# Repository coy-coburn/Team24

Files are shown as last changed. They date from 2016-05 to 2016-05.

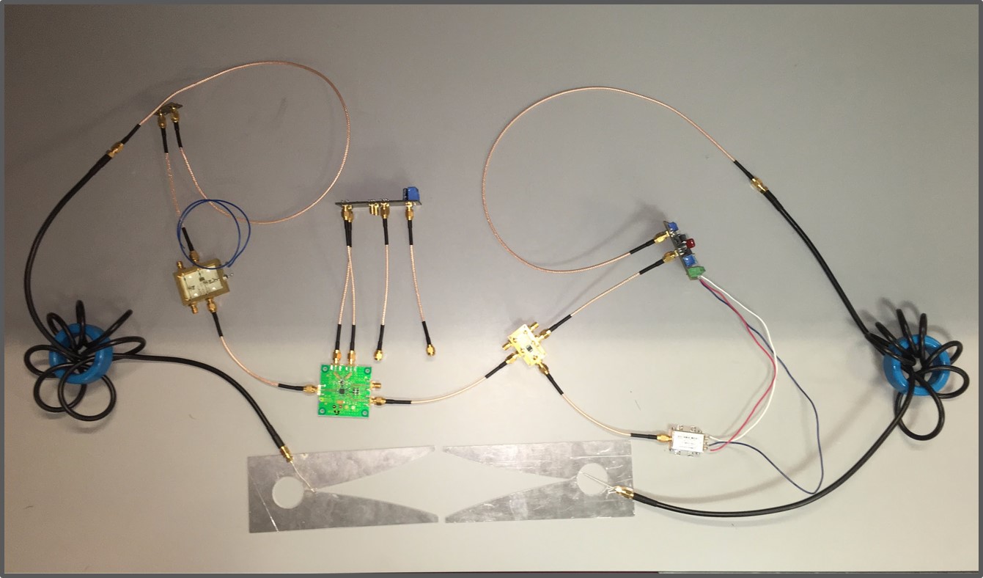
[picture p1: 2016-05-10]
photos/System.jpg

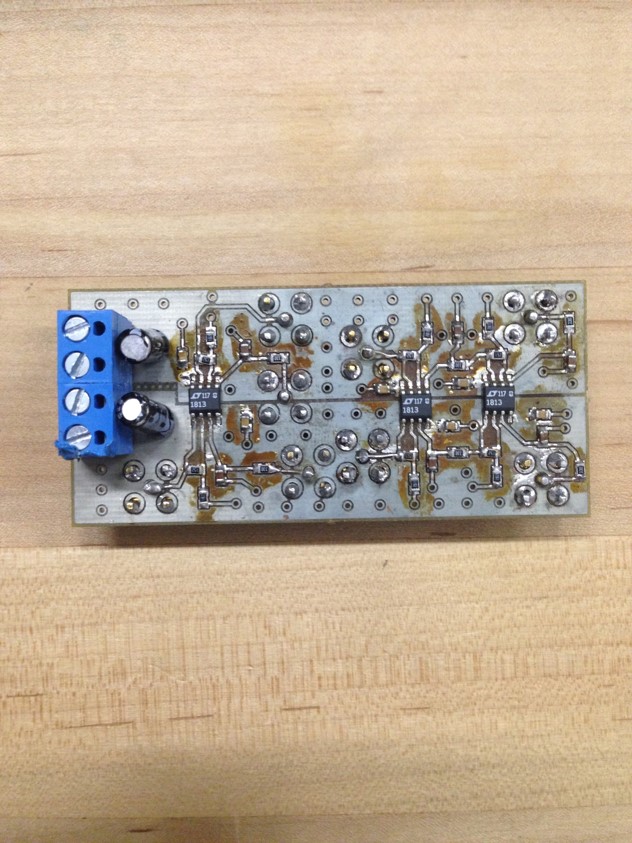
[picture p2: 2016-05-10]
photos/Filter.jpg

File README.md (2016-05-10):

# Ground Breakers
####Ground Penetrating Radar Github

The goal of this project is to create a ground penetrating radar system to serve as a non-destructive method for mapping plant root systems. The system consists of a transmitting and receiving antenna and circuitry for both the transmitter and receiver. The transmitting circuit generates a linear frequency-modulated continuous wave from 2.415- 2.425GHz. The wave is pulsed to avoid interference between the transmitting and receiving antenna. The transmitting antenna passes the generated signal into the ground while the receiving antenna collects the reflected signal. The signal will reflect off materials with different dielectric constants like that of roots and pipes. The received signal will then be sent through an LNA for amplification to balance any loss of gain. The signal is also fed into a frequency mixer to correct any occured frequency shift. Finally, the IF signal is converted into digital data that will be recorded for image processing.

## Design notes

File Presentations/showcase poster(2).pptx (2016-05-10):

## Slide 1

Root Mapping with Ground Penetrating Radar
Sponsor: Dr. Mark Everett (GEOP)
Professor: Dr. Chadi Geha TA: Neal Hollingsworth
Team members: Tyler Castro, Coy Coburn, Daniel Miller, Michael Turner

Abstract/Overview
A ground penetrating radar system (GPRS) detects objects beneath the surface by measuring a reflected electromagnetic wave and matching the reflected signal with the incident wave. After data processing, an object's depth and even the object’s material can be determined. This helps geophysics to map root growth over a period of time in a nondestructive way. Unlike other GPRS, our system uses higher frequencies (2.415-2.425GHz) in order to improve resolution.

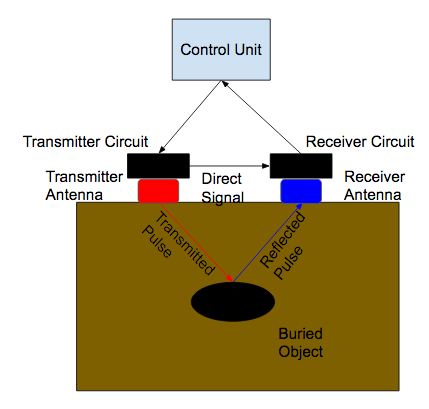
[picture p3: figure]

Figure 1. General Concept of GPRS

Signal Generation
(Linear Frequency Modulated Waveform)
A linear frequency modulated waveform is generated using a function generator and a Voltage Controlled Oscillator (VCO). This type of waveform is generated so that the frequency domain can be utilized versus the time domain. This is important in that as a signal passes through different media, the frequency of the signal remains constant. This allows the frequency to be matched on the received side so that time and amplitude can then be measured more accurately versus the time domain.

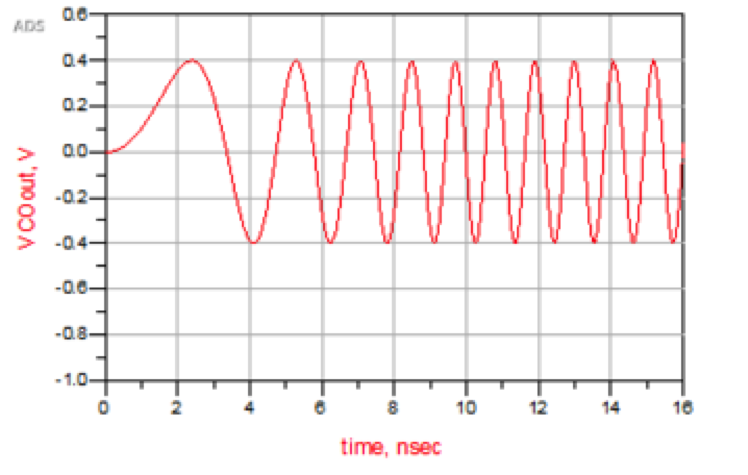
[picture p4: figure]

Figure 5: Linear Frequency Modulated Waveform

Receiver Protection and LNA
Before the signal is passed to the mixer it is conditioned to make use of the whole dynamic range of the AD converter. This is done by passing the signal through an LNA (Low Noise Amplifier). To protect the LNA from high power spikes, such as ones generated by the air to ground reflection, a schottky diode clamp is added between the LNA and the antenna. The schottky activation range is between the LNA compression point and the LNA maximum input power. LNA compression point is calculated by taking the difference between the output power at 1dB compression and the gain obtained by the LNA

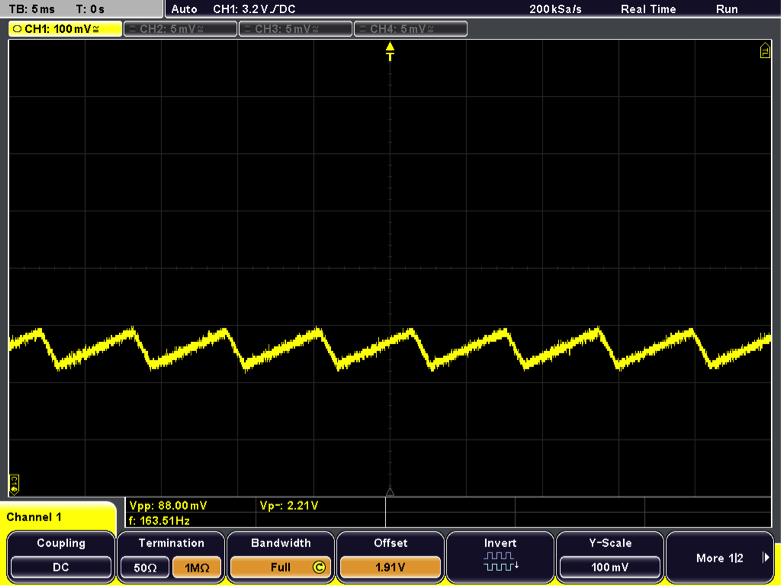
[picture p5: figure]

Figure 4: Function Generator output

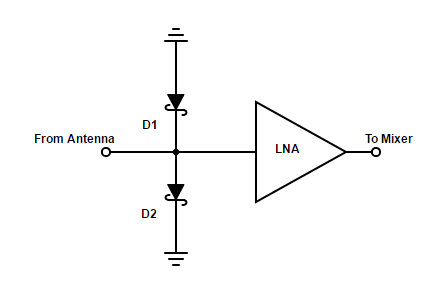
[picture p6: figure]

Figure 7. Receiver Protection and LNA circuit

AD Conversion
The filtered IFP and IFN are passed through the ADC driver for buffering and adjusting amplitude before reaching the ADC. A AAF is also included to ensure the cutoff frequency from previous stages is still entailed. Finally, an ADC with at least twice the sampling rate of the Nyquist frequency, in this case the bandwidth, is used to get the needed samples to accurately convert the analog signal into its digital counterpart.

Vivaldi Antennas
Two Vivaldi Antennas set to transmit at a frequency between 2.4025 - 2.4775 GHz. The antennas operate as a slot hole that increases in width exponentially, eventually matching the impedance of the signal with air. Ferrite cores were used to create RF chokes which acted as baluns for the system, allowing for the unbalanced coaxial cable to transition into the balanced antenna.

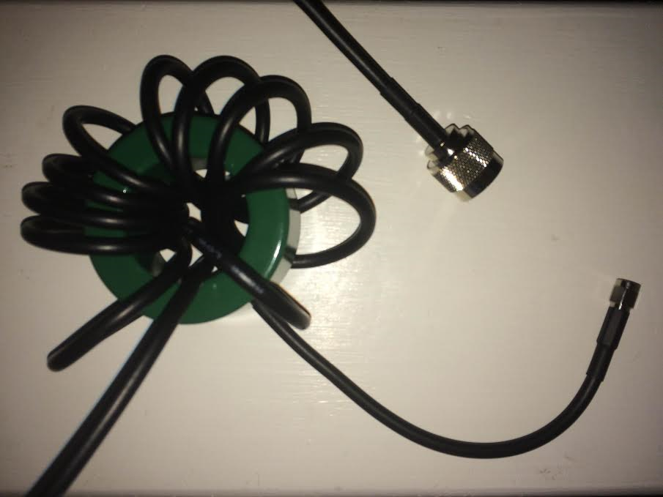
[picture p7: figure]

Reflected Signal Mixing and Filtering
Once the Rx has been amplified by the LNA, it must be mixed with the original baseline transmitted signal. Feeding the Rx into the RF input and the Tx into the LO port, an IF signal is produced. The signal is output in differential components to provide noise immunity as well as a cancellation on even-order harmonics. Calculations illustrate an expectec IF signal of 200kHz.
The IF outputs are passed through a filtering stage for image rejection. Cutoff frequencies of 250 kHz are chosen to not only prevent the up conversion image to pass, but also to protect from any unexpected IF spikes during changes in rising and falling RF/LO frequencies.

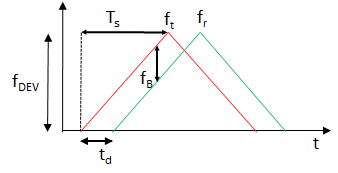
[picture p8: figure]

Figure 6. Frequency vs Time representation of LO signal compared to the RF signal

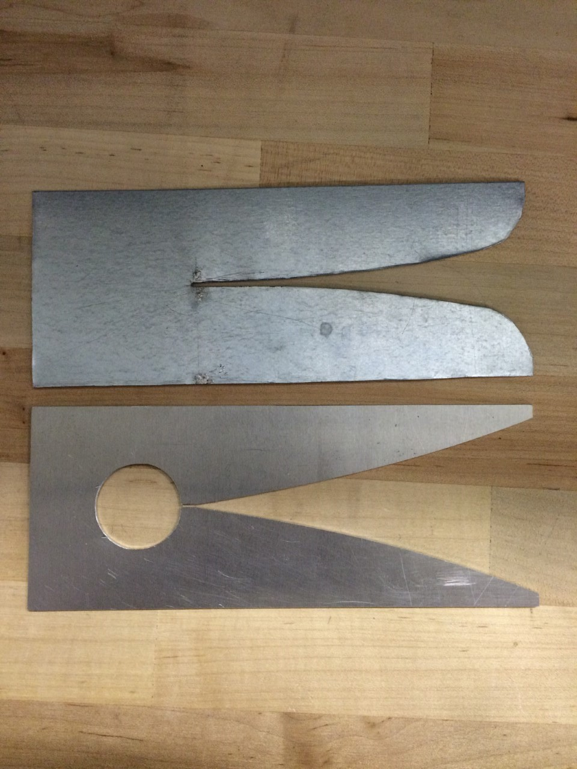
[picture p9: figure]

Figure 2. Vivaldi antennas, version 1 (top) and version 2 (below).
Figure 3. Ferrite core with coaxial cable wrapped around it, creates reactance along the outside of the cable

Rx MIXER

LO

Power Splitter

Receiver Conversion Subsystem

Figure 8. Receiver subsystem block diagram

Schottky

LNA

RF

IFP
IFN

LPF

ADC Driver

AAF

ADC

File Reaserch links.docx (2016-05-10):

http://www.geo-sense.com/GPRmore.htm - brief GPR description

http://compass.astm.org/EDIT/html_annot.cgi?D6432+11 - long detailed GPR descriptions - has many useful charts

http://www.sensoft.ca/FAQ.aspx - GPR stuff

http://georadar.150m.com/ - GPR stuff

http://epubs.surrey.ac.uk/973/1/fulltext.pdf - Long paper on GPR mostly about antennas - also old so not a lot of the data may be relevant today

http://www.sic.rma.ac.be/~scheers/Papers/chapter2.pdf - GPR design

http://d2dtl5nnlpfr0r.cloudfront.net/tti.tamu.edu/documents/1702-S.pdf - GPR Prototype development

http://ieeexplore.ieee.org/xpl/login.jsp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 - Essentially Referenced by all papers I found. The godfather of the Vivaldi Antenna

http://www.rfwireless-world.com/calculators/slotline-calculator.html - slotline equations

http://www.antenna-theory.com/antennas/aperture/vivaldi.php - makeshift vivaldi antenna guide

http://www.jpier.org/PIER/pier82/26.08040601.pdf - Exponential curve equations

https://www.eznec.com/Amateur/Articles/Baluns.pdf - Helpful reference for baluns

http://www.jpole-antenna.com/2012/07/03/why-build-antennas-out-of-copper-and-not-aluminum-or-stainless-steel/ - Quick advice on material choice (hint: don't pick aluminum)

http://www.futureelectronics.com/en/diodes/schottky-diodes.aspx - Schottky Diode description

https://www.ieee.li/pdf/essay/pin_diode_handbook.pdf - PIN Diode Handbook

http://publications.lib.chalmers.se/records/fulltext/163250.pdf - Fast PIN Diode driver design

http://www.analog.com/library/analogDialogue/archives/44-02/pin_diode.html - PIN Diode Driver

http://www.ittc.ku.edu/~jstiles/622/handouts/Receiver%20Compression%20Point.pdf – Receiver Compression

http://www.microwaves101.com/encyclopedias/compression-point - Compression Point

http://cp.literature.agilent.com/litweb/pdf/5965-8166E.pdf - Using Network Analyzer

http://www.analog.com/library/analogDialogue/archives/39-06/Chapter%205%20Testing%20Converters%20F.pdf – Analog digital conversion

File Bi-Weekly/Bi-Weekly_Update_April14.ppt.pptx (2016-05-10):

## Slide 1

Team 24 - Ground Penetrating Radar

Members: Tyler Castro, Coy Coburn, Daniel Miller, and Michael Turner

Design and simulate subsystems | Buy necessary hardware | Incorporate transmitter circuit and antenna | Incorporate receiver circuit and antenna | Integrate subsystems and testing with network analyzer

Transmitter Circuit

Transmitter Antenna

Control Unit

Direct Signal

Receiver Circuit

Receiver Antenna

Transmitted Pulse

Reflected Pulse

Buried Object

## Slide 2

Signal Generation Daniel Miller

Accomplishments since the last presentation ~35 hrs | Ongoing progress/problems and plans until the next presentation
Finished PCB Needs decoupling Tested Function Generated 5 MHz Bandwidth (80 mVpp) Voltage divider Start of ISM band (2V) Op-Amp | Solder PCB Prepare for Demo Problem: Excess Noise

VCO frequency equation:
frequency = 68.065 (Voltage) + 2268.8

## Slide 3

Output from Op-Amp

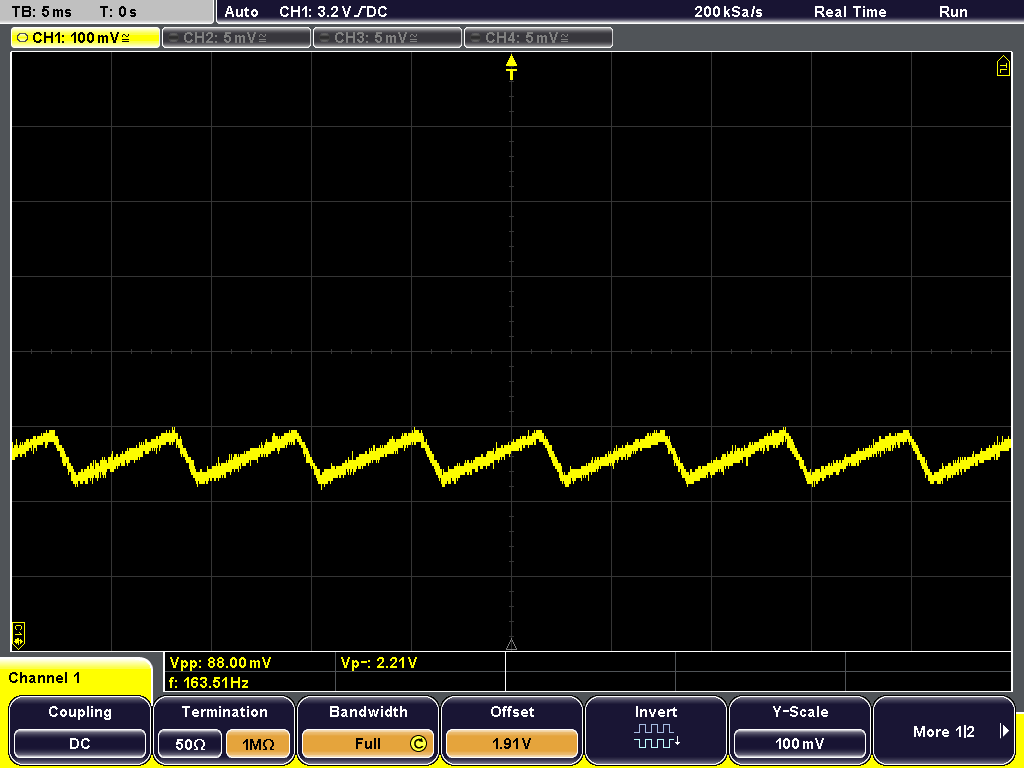
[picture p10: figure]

Vpp = 88mV
Vp = 2.21 V

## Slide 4

Antennas Tyler Castro

Accomplishments since the last presentation 30 hrs | Ongoing progress/problems and plans until the next presentation
Tested antenna created by hand Used Solidworks to create files for having the antennas made with the mill Currently working to ensure antennas get cut Ordered parts for demo | Ensure antennas are created in order to begin immediate testing Prepare for demo

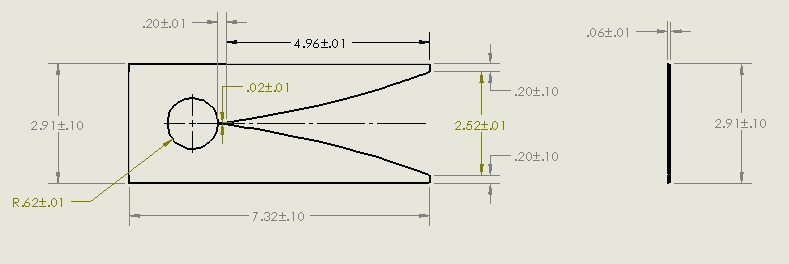
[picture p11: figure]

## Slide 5

Receiver Circuit Michael Turner

Accomplishments since the last presentation 20 hrs | Ongoing progress/problems and plans until the next presentation
Finished ordering parts and SMA cables Designed and received PCB Assisted Coy with redesign of receiver conversion and PCB design | Solder PCB Test Schottky diodes and LNA Work with Coy with integrating the receiver together

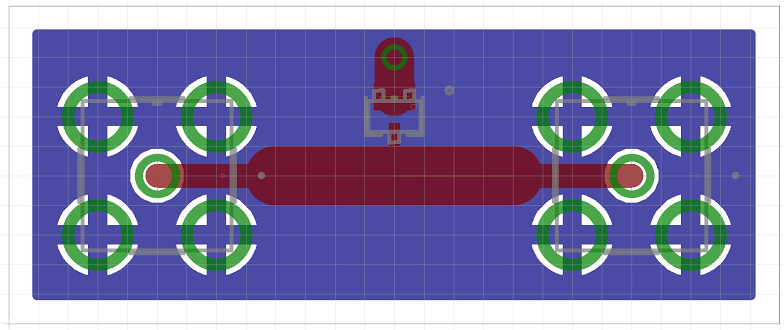
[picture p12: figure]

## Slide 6

Receiver Conversion Coy Coburn

Accomplishments since the last presentation 32 hrs | Ongoing progress/problems and plans until the next presentation
Redesigned and simulating receiver schematic Recalculated sampling rate data based on new bandwidth of 5MHz Bought chips,eval boards, and other hardware Designed and received PCB Found and bought power divider | Check necessary gain and corner freuencies for each LPF/AAF stage Locate ADC eval board and test digitization with Analog Visual Test ADC driver output Integrate circuit with Michael’s LNA/Schottky circuit

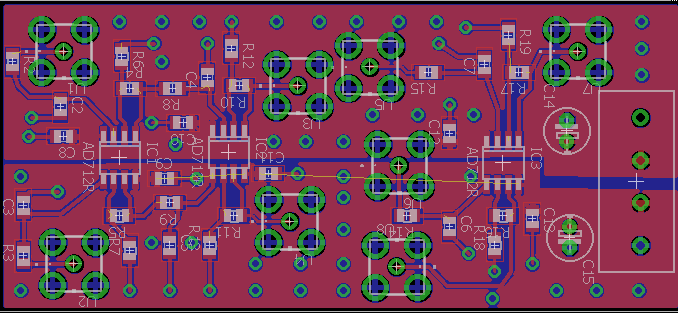
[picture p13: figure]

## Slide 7

Block Diagram and Parts Table

SHIELD

Schottky

IMAGE
REJECT
FILTER (LPF)

ADC Driver

AAF/LPF

LNA

Rx MIXER

IF Amp

LPF

ADC

Gain Block

Power Splitter

SHIELD

Block | Part number
Rx Mixer | ADL5363
Gain block | ADL5611
Low pass filter (LPF) op amps | LT1813
ADC Driver | AD8138
ADC | AD9280
Power Splitter | BP2U+

Gain Block

SHIELD

## Any Questions?

Thanks and Gig em’

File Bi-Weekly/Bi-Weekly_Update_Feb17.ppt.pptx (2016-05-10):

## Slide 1

Team:24 Ground Penetrating Radar

Design and simulate subsystems | Buy necessary hardware | Install transmitter and phased array antenna | Install receiver and phased array antenna | Integrate subsystems and testing with network analyzer | Design image processing system (if time)

Transmitter Circuit

Transmitter Antenna

Control Unit

Receiver Circuit

Receiver Antenna

Direct Signal

Transmitted Pulse

Reflected Pulse

Buried Object

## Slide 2

Power/Signal Generation Daniel Miller

Accomplishments since the last presentation ~20 hrs | Ongoing progress/problems and plans until the next presentation
Redefined requirements Power loss through media (not good estimate) Researched other ways to achieve bandwidth (DDS/NCO) | Meet with Professor Nevels Obtain antenna info (sensitivity/gain) Calculate power needed at output Power needed through system (PA)

Transmitter Circuit

Transmitter Antenna

Receiver Circuit

Receiver Antenna

Transmitted Pulse

Direct Signal

Reflected Pulse

Buried Object

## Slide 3

Receiver Circuit Michael Turner

Accomplishments since the last presentation 20 hrs | Ongoing progress/problems and plans until the next presentation
Redesigned Receiver circuit Bought LNAs Found possible PIN Diodes Research PIN Diode driver | Design PIN Diode Driver Decide on PIN Diode and order all parts

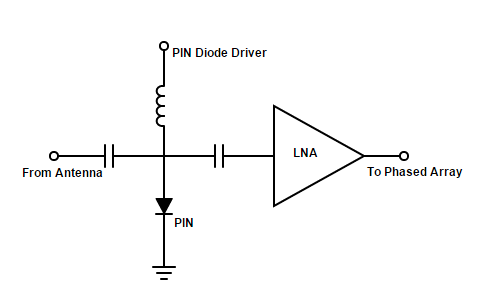
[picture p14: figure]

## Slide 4

Receiver Antenna Coy Coburn

Accomplishments since the last presentation 15 hrs | Ongoing progress/problems and plans until the next presentation
Calculated/bought necessary coax cable to create phase shifters Designing/simulating summing amp Researching mixers and IQ demodulation | Finalize receiver schematic Choose and order IQ demodulator and mixers (if needed)

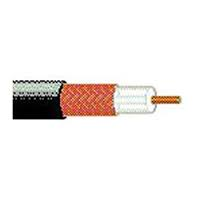
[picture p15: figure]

Belden 9258 specs:
Impedance: 50 Ω
Propagation Velocity: %82
Nominal Attenuation: 10.7 dB/100 ft @ 900 MHz
Price: $0.82 per ft

Length of coax: d = (Vf*c/ƒ)*(Θ/360)

30° | 45° | 60° | 90°
2.24 cm | 3.36 cm | 5.04 cm | 6.72 cm

Phase shift:
Length:

180°
13.44 cm

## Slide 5

Transmitting Antenna Tyler Castro

Accomplishments since the last presentation 15 hrs | Ongoing progress/problems and plans until the next presentation
Decided on specific amplifiers for gain stages Using Vivaldi antennas for directivity, simplicity and cost of construction Calculated design parameters for Vivaldi antennas | Order components to begin construction Design balun to prevent current from travelling along outside of coaxial cable at antenna connection

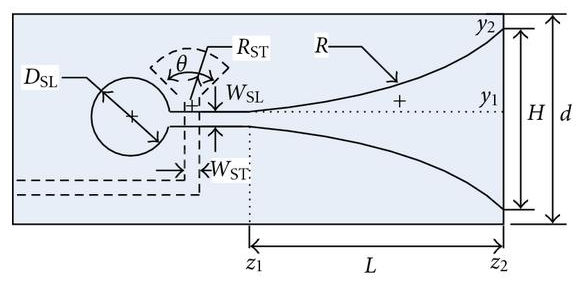
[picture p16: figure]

Vivaldi Antenna, facing right
For 700 MHz:
H = 8.44 inches
L = 16.87 inches
Dsl = 2.48 inches

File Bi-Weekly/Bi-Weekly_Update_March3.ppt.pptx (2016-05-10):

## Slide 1

Team:24 Ground Penetrating Radar

Design and simulate subsystems | Buy necessary hardware | Install transmitter and phased array antenna | Install receiver and phased array antenna | Integrate subsystems and testing with network analyzer | Design image processing system (if time)

Transmitter Circuit

Transmitter Antenna

Control Unit

Direct Signal

Receiver Circuit

Receiver Antenna

Transmitted Pulse

Reflected Pulse

Buried Object

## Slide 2

Receiver Circuit Michael Turner

Accomplishments since the last presentation 20 hrs | Ongoing progress/problems and plans until the next presentation
Added schottky diodes to protect LNA Ordered schottky diodes Work on simulation for PIN Diode driver | Finish PIN diode driver simulation Design PCB board Work with Coy to combine LNA and diode circuit with demodulator

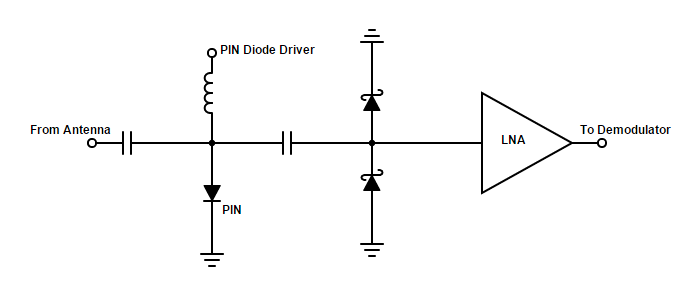
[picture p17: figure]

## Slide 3

Receiver Antenna Coy Coburn

Accomplishments since the last presentation 17 hrs | Ongoing progress/problems and plans until the next presentation
Redefined goals for GPR system Helped set excel doc to calculate needed variables Researching mixers and IQ demodulation | Finalize receiver schematic Choose and order IQ demodulator and ADC Work with Michael to combine LNA and diode circuit with demodulator

Sample rate(Fs): 2 * BW = 150 MHz = 150 Msamples/sec
Slope (freq/time): BW / 4 * TOF = 1.9 E 15 Hz/s
Freq resolution(Δf): (2*spatial resolution/ Vs)* Slope = 2.4MHz
Δf = 1/T T = #samples / Fs
#samples = 62.5 => 63 samples

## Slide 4

Transmitting Antenna Tyler Castro

Accomplishments since the last presentation 15 hrs | Ongoing progress/problems and plans until the next presentation
Purchased metal sheets and tools, began construction of prototype antenna Ordered balun parts | Finish construction, solder balun and begin running tests using network analyzer Use data to improve design

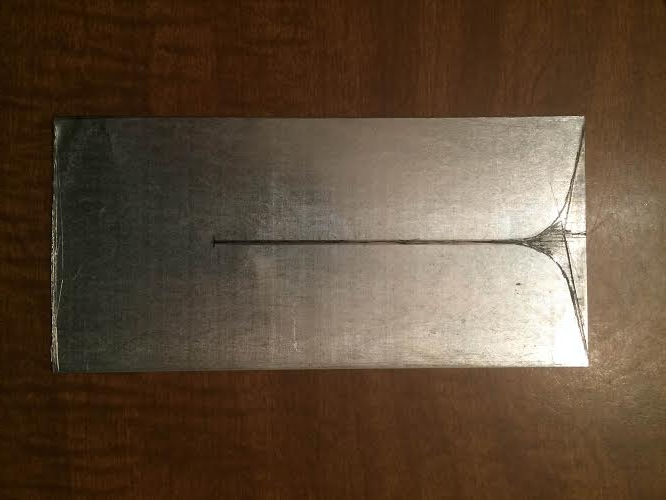
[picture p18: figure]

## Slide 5

Power/Signal Generation Daniel Miller

Accomplishments since the last presentation ~15 hrs | Ongoing progress/problems and plans until the next presentation
Ordered function generator up to 1 MHz meets pulse duration requirement (duty cycle) Ordered VCO ISM band 2-2.5V Minimum of 50 mW output for antennas | Test outputs from VCO Select/Order PA Think about portable power supply

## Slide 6

Function Generator circuit

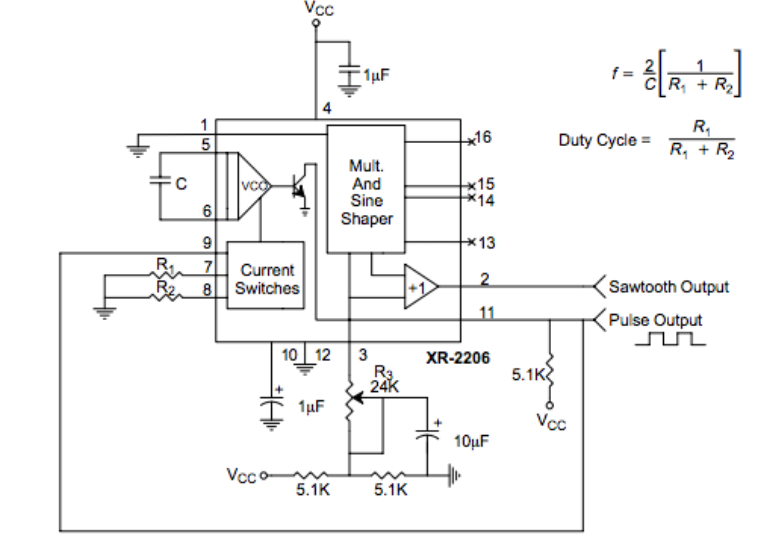
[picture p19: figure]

Jameco XR-2206 Data sheet

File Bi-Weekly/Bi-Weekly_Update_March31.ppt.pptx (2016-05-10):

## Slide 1

Team 24 - Ground Penetrating Radar

Design and simulate subsystems | Buy necessary hardware | Incorporate transmitter circuit and antenna | Incorporate receiver circuit and antenna | Integrate subsystems and testing with network analyzer | Design image processing system (if time)

Transmitter Circuit

Transmitter Antenna

Control Unit

Direct Signal

Receiver Circuit

Receiver Antenna

Transmitted Pulse

Reflected Pulse

Buried Object

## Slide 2

Power/Signal Generation Daniel Miller

Accomplishments since the last presentation ~18 hrs | Ongoing progress/problems and plans until the next presentation
Ordered PAs (Approx 1 W) 24 dB gain Output +26dBm Tested VCO (broken) Soldered wires to inputs Stripped coaxial to wire for testing Talked with manufacturer to ship new part Started PCB design | Test VCO .5-5V Vtune Finish designing PCB Test Function generator Think about portable power supply

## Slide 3

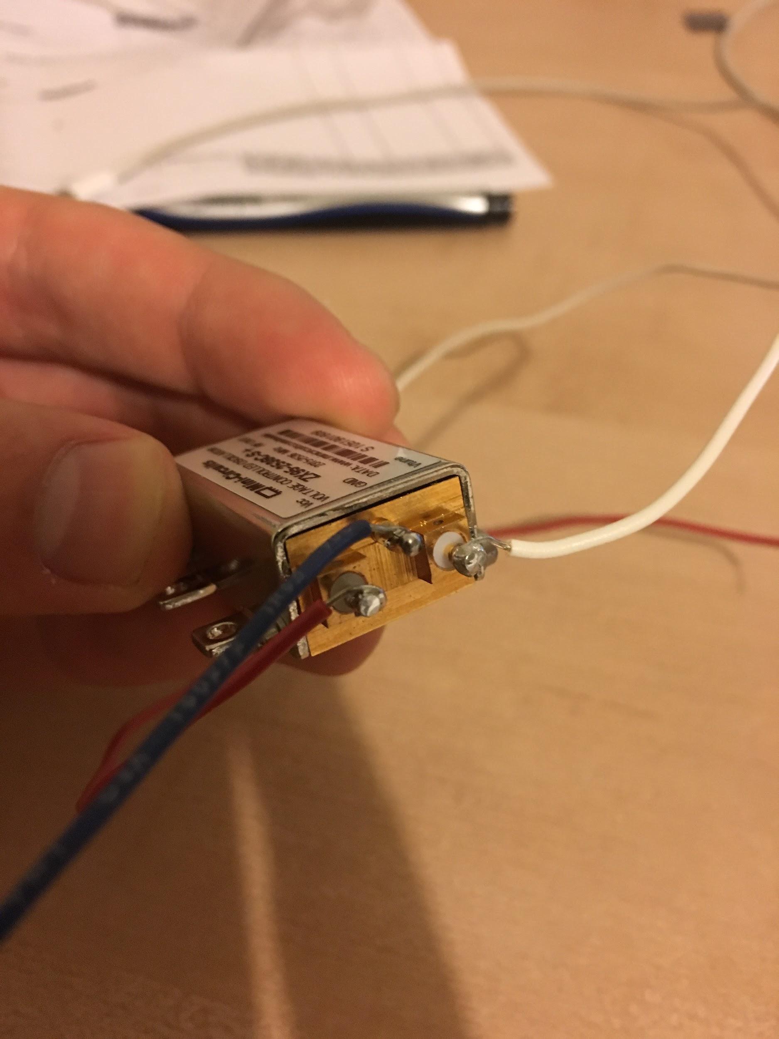
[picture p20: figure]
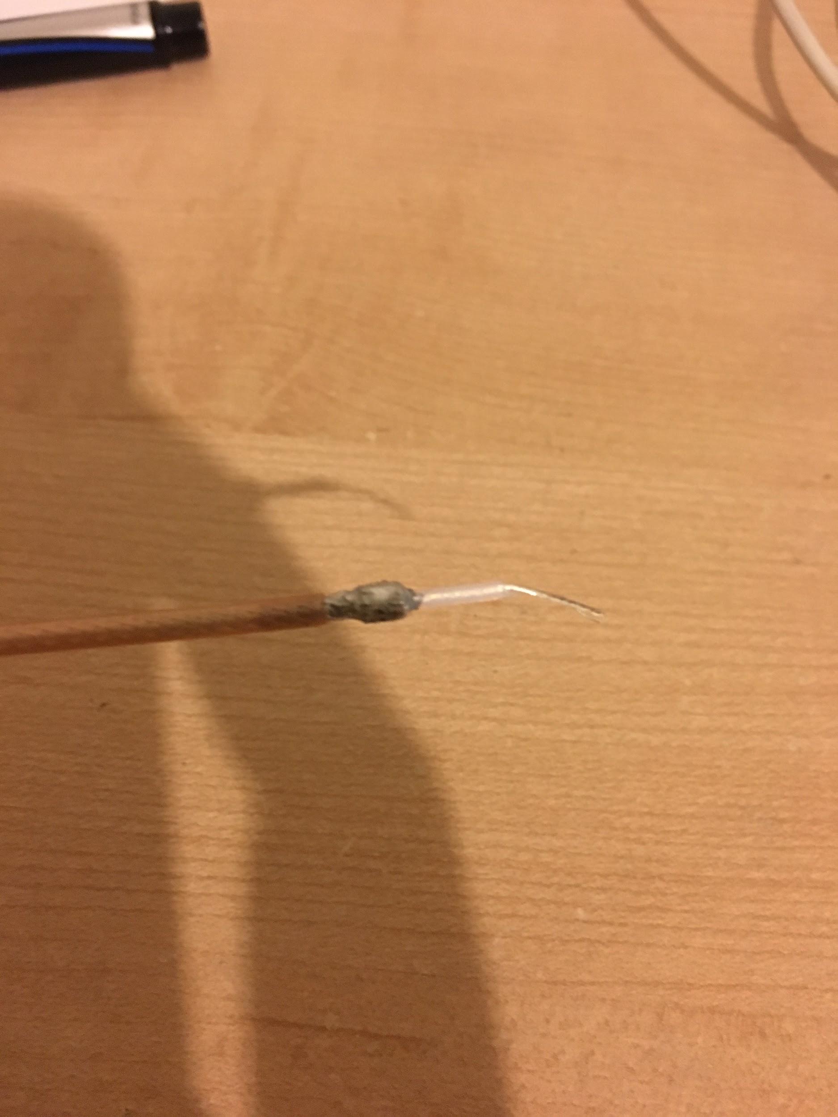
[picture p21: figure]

SMA to wire termination

GND

Vtune

Vcc

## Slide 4

Antennas Tyler Castro

Accomplishments since the last presentation 20 hrs | Ongoing progress/problems and plans until the next presentation
Vivaldi antenna cut to proper curve shape Obtained SMA Female Cable, N-type/SMA Male Cable, Ferrite Toroidal Core SMA Cable soldered to gap of antenna and balun assembledy, ready for testing | Begin testing using network analyzer Depending on the results of testing, either Alter current design to increase effectiveness Move toward developing a more compact balun

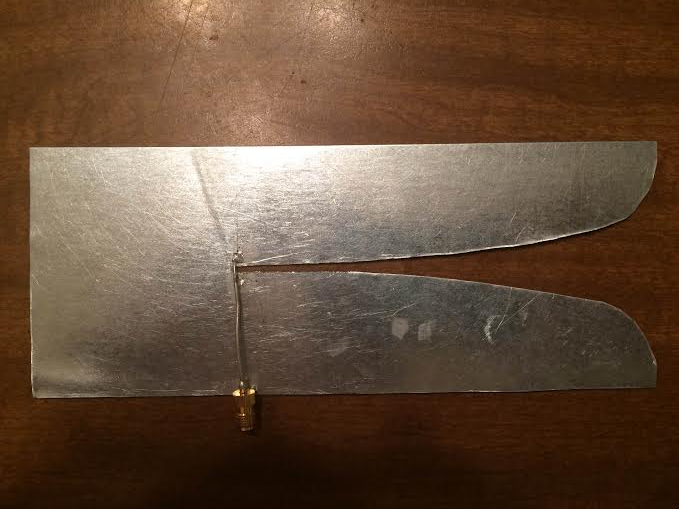
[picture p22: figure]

Left: Vivaldi antenna with SMA-cable soldered Right: N type-SMA cable wrapped around ferrite core

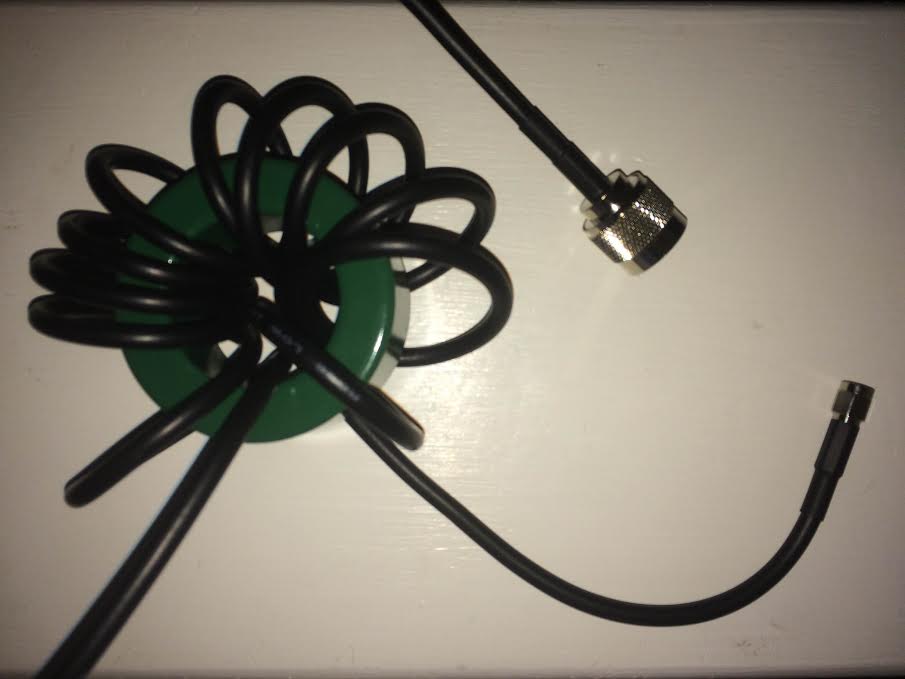
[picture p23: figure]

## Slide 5

Receiver Circuit Michael Turner

Accomplishments since the last presentation 20 hrs | Ongoing progress/problems and plans until the next presentation
Removed PIN diode from receiver circuit Ordered and received new LNA Helped Coy with redesign of receiver conversion Started PCB design | Finish PCB design Test Schottky diodes and LNA Work with Coy with integrating the receiver together


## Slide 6

Receiver Conversion Coy Coburn

Accomplishments since the last presentation 18 hrs | Ongoing progress/problems and plans until the next presentation
Redesign schematic for subsystem Calculating max bandwidth frequency and mixing spurs Chosen frequency mixer, calculating specs needed for LPF and ADC | Finalize receiver schematic Choose and order LPF and ADC Design buffer to handle ADC driving impedance Integrate circuit with Michael’s LNA/Schottky circuit

Mixer

LO

Low pass filter

Buffer

ADC

RF

IF

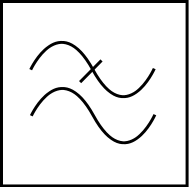
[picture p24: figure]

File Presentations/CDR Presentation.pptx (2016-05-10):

## Ground Penetrating Radar

Control Unit

Team 24
Tyler Castro
Coy Coburn
Daniel Miller
Michael Turner

Transmitter Circuit

Transmitter Antenna

Receiver Circuit

Receiver Antenna

- Objective: To map underground root systems
- The transmitter will pulse a signal to penetrate the ground.
- The receiver will take the reflected signal.
- The control unit will display the created radar image and record an image log.
- The main feature of this GPR system is the phased array antennas.

Direct Signal

Transmitted Pulse

Reflected Pulse

Buried Object

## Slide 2

Subsystem | Primarily Responsible Team Member | Student Responsibilities/ Tasks
Transmitter Circuit | Tyler | Design and implement the circuit to transmit the RF signal as well as utilize pulse compression via chirping the signal.
Transmitter Antenna | Daniel | Design phased array antenna for generating signal
Receiver Antenna | Coy | Successfully catch reflected signals and mix said signals for A/D conversion.
Receiver Circuit | Michael | Design the receiver components and verify that they adjust the signal properly before mixing.
Control Unit | Coy | Allow for user manipulation of the GPR device and image processing for the radar display.

## Tyler Castro

- A modulator generating a sawtooth signal is connected to a voltage controlled oscillator
- Resulting signal is a linearly modulated chirp, with frequency from 902 to 930 MHz
- A chirp allows for better filtering on the receiving end

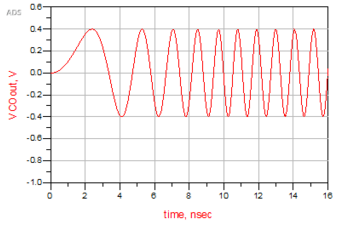
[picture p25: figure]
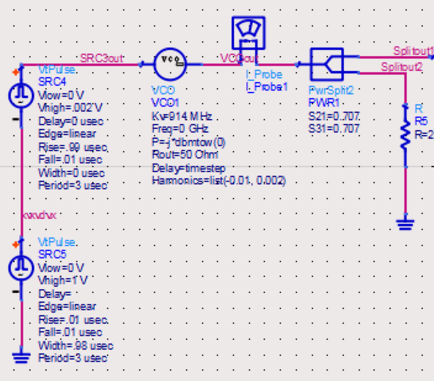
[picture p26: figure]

## Daniel Miller


- Splitter for sending to a mixer on the receiving end
- Attenuator for impedance matching
- Amplifier S-parameters based off of an PA of 11 dB gain, ZX60-3011+

## Daniel Miller


- 50 ohm resistors used to represent antenna load
- Phase shifters used to direct or focus antenna pattern

## Coy Coburn


- The phased array on the receiver side utilizes the homodyne design
- Initial simulations involve a decaying sine wave with pulses to represent reflected signals from objects
- Incoming reflections will be mixed with the original generated signal for matched filtering


## Michael Turner


## Gantt Chart


## Summary/Conclusion

In summary, both the transmitter and receiver subsystems are the main focus for the team as a whole at the moment. Once simulations have been finalized, hardware will be bought and installed which will occupy most of the semester. The control unit subsystem will then be the main priority along with field testing of the GPR. While there is much work that still needs to be done, progress so far is encouraging.

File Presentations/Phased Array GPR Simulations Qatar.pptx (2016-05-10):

## Phased Array GPR Simulations

Team 24
Presenter: Coy Coburn
Partners: Michael Turner, Daniel Miller, Tyler Castro

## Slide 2

Control Unit

GPR Overview

- Objective: To map underground root systems
- The transmitter will pulse a signal to penetrate the ground up to 1 meter.
- The receiver will take the reflected signal.
- The control unit will display the created radar image and record an image log.
- The main feature of this GPR system is the phased array antennas.

Transmitter Circuit

Transmitter Antenna

Receiver Circuit

Receiver Antenna

Direct Signal

Transmitted Pulse

Reflected Pulse

## Receiver Circuit Implementation

- The Time Varying Gain is included before the Low Noise Amplifier.
- The TVG weighting must be chosen depending on the soil type.
- Each reflection picked up by the antennas are amplified before mixed to simplify design.


## Radar Display

- Below is an example of the expected signal to be received.
- This test signal is made by pulsing a decaying sine wave.
- The medium (ground) usually does not return much reflection after entering the ground.


[1] Scheers, Bart taken from http://www.sic.rma.ac.be/~scheers/Papers/chapter2.pdf


## Time Varying Gain

- Farther distance leads to a weaker reflection
- A time varying gain is utilized to amplify weaker reflections
- TVG is very similar to the Automatic Gain Control


## Transmitter with Chirp Simulations


Input signal into the VCO


## Citations

[1] Bart Scheers, “Ultra-Wideband Ground Penetrating Radar, with Application to the Detection of Anti Personnel Landmines,” Ph.D. dissertation, Dept. Elect. Eng, Catholic Univ. of Louvain, Louvain-la-Neuve, Belgium, 2001.
[2] C. Allen , “Radar Pulse Compression ,” 2004. [Online]. Available at: https://www.ittc.ku.edu/workshops/Summer2004Lectures/Radar_Pulse_Compression.pdf. [Accessed: 2015]
[3] Cedric Martel, “Modelling and Design of Antennas for Ground-Penetrating Radar Systems ,” Ph.D. dissertation, Dept. Elect. Eng, Univ. of Surrey, Guildford, United Kingdom, 2002.
[4] “Ground Penetrating RADAR (GPR) (After Basson 2000) Introduction,” GPR theory, 2007. [Online]. Available at: http://www.geo-sense.com/gprmore.htm. [Accessed: Dec-2015].

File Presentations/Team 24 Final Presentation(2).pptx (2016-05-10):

## Team 24 Proposal Presentation

Phased Array GPR Simulations
Daniel Miller
Tyler Castro
Michael Turner
Coy Coburn

## GPR Block Diagram

- Objective: To map underground root systems
- The transmitter will pulse a signal to penetrate the ground.
- The receiver will take the reflected signal.
- The control unit will display the created radar image and record an image log.
- The main feature of this GPR system is the phased array antennas.

Control Unit

Direct Signal

Transmitter Antenna

Receiver Antenna

Transmitted Pulse

Reflected Pulse

Buried Object

## Transmitting Antenna


## Chirp Generator


Chirp example

Input signal into the VCO


## Splitter, Attenuator, Amplifier

- Splitter for sending to a mixer on the receiving end
- Attenuator for keeping a low VSWR
- Amplifier S-parameters based off of an LNA of 11 dB gain, ZX60-3011+


## Antenna Array with Phase Shifters


- 50 ohm resistors used to represent antenna load
- Phase shifters used to direct or focus antenna pattern

## Antenna Type

Vivaldi antenna
1. Directive
2. Low-cost
3. Able to be constructed, if necessary
4. Frequency dependent on construction


## Receiver Block Diagram


- The receiver picks up the reflected signals.
- We chose the Homodyne version over the Heterodyne phased array to avoid the need to utilize multiple LO with each incoming signal.
- We want to amplify before mixing samples so we do not lose any reflections.
- The four main blocks that make up this circuit are the TVG, LNA, SH, and ADC


## Circuit Implementation

- We decided to implement a passive array due to cost restraints.
- The TVG is included before the LNA so that its design can be much more sensitive without saturation of the air and ground.
- Overall, this increases the dynamic range of the receiver.


## Radar Display

- Below are examples of the expected signals to be received. The first example is a basic signal, while the second one is the reflection from multiple signals.


## Receiver test signal

- This test signal is made by pulsing a decaying sine wave.
- This is due to the farther away an object is, the weaker the reflected signal will be.
- The medium (ground) usually does not return much reflection after entering the ground.


## Time Varying Gain

- Farther distance = weaker reflection
- Therefore, a time varying gain is needed to compensate for the signal. In theory, all reflections should be of the same amplitude.
- TVG is very similar to the Automatic Gain Control


## TVG output

- While the TVG test does amplify the reflected signals, it needs to be uniform. The TVG function will need to be tweaked depending on the decay rate.


## Low Noise Amplifier

- The LNA’s purpose is to get full use of the RF’s dynamic range.
- With the LNA following the TVG, it can now be much more sensitive without saturating the reflections.
- Simulation S values were found from a transceiver BFP 420 datasheet, for up to 10 GHz


## Sample and Hold

- Our SH circuit takes samples from the outgoing LNA signal in reference to the rising edge of its given CLK signal.
- The clock is usually based on the transmitter’s timing. We will need to match this in later versions
- Overall, it slows down the sampling rate for the Ad converter


## THANKS AND GIG EM

Questions?

## Backup slides

1. Antenna shielding
2. SH circuit diagram
3. Active vs passive array

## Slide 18


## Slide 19

Full bridge SH, used for under 1 GHz


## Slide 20

Passive phased arrays have a central transmitter and receiver, with phase shifters located at each radiating element or subarray. The passive array is the least expensive phased array because of its low number and cost of components1 . Active arrays use Transmit/Receive (T/R) modules to provide the last stage of amplification for transmitted signals, the first stage of amplification for receive signals, and provide both amplitude and phase control at each radiating element. The use of T/R modules in active arrays provides the advantages of amplitude control, low loss, and graceful degradation over passive arrays. Given these advantages, one could assume that all phased arrays in development are active.

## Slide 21

The noise figure is the difference in decibels (https://en.wikipedia.org/wiki/Decibel) (dB) between the noise output of the actual receiver to the noise output of an “ideal” receiver with the same overall gain (https://en.wikipedia.org/wiki/Gain_(electronics)) and bandwidth (https://en.wikipedia.org/wiki/Bandwidth_(signal_processing)) when the receivers are connected to matched sources at the standard noise temperature (https://en.wikipedia.org/wiki/Noise_temperature) T0 (usually 290 K).

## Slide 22

Older adc cannot handle conversion rates of 200 MHz for 8 bit and 10 MHz for 16 conversions. However, newer models may have built SH already in their circuits.

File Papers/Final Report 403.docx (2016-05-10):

# GPR Root Mapping System

# Team 24

# Final (Progress) Report

ECEN 403 – Capstone (Senior) Design Project

Texas A&M University, College Station, TX

Tyler Castro

Coy Coburn

Daniel Miller

Michael Turner

Abstract

This document focuses on the project overview and each of the subsystems (transmitting/receiving antenna) involved in the ground penetrating radar root mapping system. The transmitting antenna incorporates pulse compression by generating chirps, this in turn creates a linearly frequency modulated signal. This signal is passed to the data processing side for phase matching and to the phased array antennas. The phased array antennas will directionally aim the signal into the ground for better penetration depth and resolution. The receiving antenna will pick up the resulting echoes created from the transmitter antenna’s signal colliding into an object as well as the ground itself, and reflected back. These reflections will be processed and amplified for digital conversion. These resulting digital signals will be processed into images for the display.

Table of Contents

Abstract

Table of Contents

1 Project Overview

1.1 Current System Design

1.2 Project Deliverables

1.3 Definition of Interfaces

1.4 Task Ownership

2 Individual Contributions Transmitting Antenna

2.1 Significant Changes in Direction

2.2 Subsystem Status

2.3 Subsystem Challenges and Solutions

2.4 Subsystem Technical Details

2.5 Subsystem Testing

3 Individual Contributions <Subsystem #2 Name>

3.1 Significant Changes in Direction

3.2 Subsystem Status

3.3 Subsystem Challenges and Solutions

3.4 Subsystem Technical Details

3.5 Subsystem Testing

4 Conclusions

References

(http://#_Toc437467716)

# 1 Project Overview

The GPR root mapping systems will locate plant roots underground using radar waves emitted and received by arrays of antennas. Mathematical equations will be applied to the reflected signal so the user can interpret the data. Geophysicists can use this data to examine plant root growth over a period of time.

## 1.1 Current System Design

The transmitting antenna consists of a chirp generator, power splitter and amplifier, and a phased antenna array. The transmitting circuit must be able to generate a signal powerful enough so the receiving antennas can collect the attenuated signal.

Screen Shot 2015-11-15 at 8

Figure 1.1: System block diagram.

## 1.2 Project Deliverables

By the end of the semester, we plan to have a working radar system able to detect objects 1 meter deep in sand. Due to the complexity of most of the components and the time required to procure them ourselves, all components will be purchased online.

### 1.2.1 Subsystem Specifications

The transmitting antenna should generate a chirp with a desired voltage and current of 400mV and 4.5 mA.

This will provide a power of 675mW at each of the four antennas.

Table 1.1
Subsystem Specification Compliance Matrix

Specification | Min | Nominal | Max
Chirp Power
Power Amplifier Gain | TBD
Antenna Power

### 1.2.2 System Specifications

The TVG in the receiver subsystem should amplify the reflections based on the time received by the antenna, with an initial gain of 1 dB.

Table 1.2
System Specification Compliance Matrix

Specification | Min | Nominal | Max
TVG amplification | TBD
Antenna Power

## 1.3 Definition of Interfaces

Table 1.3
Responsibility Matrix

Subsystem | Responsible Member | Responsibilities
Transmitting Antenna | Tyler Castro Daniel Miller | Implementation of chirps Design of phase array antennas
Receiving Antenna | Coy Coburn Michael Turner | Reflection amplification Design of receiving phase array antenna Analog to digital conversion

## 1.4 Task Ownership

Tyler Castro and Daniel Miller are responsible for the transmitting antenna. This includes researching initial design and testing, as well as its physical construction and choice of components. In particular, they will need to decide on chirp values, pulse compression, and the design of the phased array antenna.

Table 1.4
Responsibility Matrix

Subsystem | Responsible Member | Responsibilities
Transmitting Antenna | Tyler Castro Daniel Miller | Full design and testing for transmitting antenna includes: Generating chirp for pulse compression Signal splitter for phase matching for receiving antennas Power amplification Design of phased array antenna Power calculations
Receiving Antenna | Coy Coburn Michael Turner | Full design and testing for receiving antenna includes: Time varying gain compensation for incoming reflections Signal mixer for incoming signal transmissions Low noise amplification Design of phased array receiver antenna Image procession

# 2 Individual Contributions Transmitting Antenna

The transmitting antenna section generates a linear chirp with an average frequency of 915 MHz with duration of 1.25 ns. These pulses will be sent through a power amplifier to be emitted by an array of four antennas. The original pulse will also be sent straight to the receiving end of the system by a power splitter for the purpose of mixing for pulse compression. All four antennas will have a phase shifter immediately before it, in order to aim and focus the pulse.

## 2.1 Significant Changes in Direction

N/A

## 2.2 Subsystem Status

Currently, the voltage and current of the generated chirp in the simulation is +/-400 mV and +/-4.5 mA. The power amplifier serves to increase the power of the signal to allow it to travel through the ground without attenuation completely destroying it. The power amplifier has a gain of 17 dB. The power currently at one antenna is 675mW, and the minimum required power to have the waves reach the receivers is 1W.

Table 2.1
<Subsystem> Specification Compliance Matrix

Specification | Min | Nominal | Max
Power from Source Power Amplifier Gain Power at Antennas (Individually) | TBD

## 2.3 Subsystem Challenges and Solutions

The biggest challenge presented in this subsystem was reaching the proper power level in order to overcome the ground attenuation. Our solution was to add phase shifters to concentrate the wave at a specific point. Proper tuning of the phase shifters allow for maximum constructive interference at a point.

## 2.4 Subsystem Technical Details

The chirp generator consists of two pulse generators in series, which create a series of linear ramps separated by a set amount of time. That function is fed into a voltage-controlled oscillator, making the generated pulses modulated linearly. Next is the splitter and power amplifier in series. The splitter sends the original pulse to the receiving end for mixing, and the power amplifier provides the gain required for the pulse to travel through the ground. The antenna array consists of a 1-4 power splitter, which leads to four separate antennas, all equipped with their own phase shifter.

Below is two tables showing values obtained during testing of the power amplifier and the voltage controlled oscillator.

Table 2.2
Power Amplifier

Parameter | Specification | Simulation Results
Gain | 11dB | 11dB
Bandwidth | 915MHz | 915MHz

Table 2.2
Voltage Controlled Oscillator

Parameter | Specification | Simulation Results
Kv | 914 MHz | 914 MHz
Frequency at 0 V | 0 Hz | 0 Hz

## 2.5 Subsystem Testing

Simulating the transmitting antenna circuit in Advanced Design System was the only testing we were able to perform on the subsystem so far.

### 2.5.1 ADS Simulation

The ADS simulation’s purpose was to confirm our architecture, as well as see the gain and loss throughout the system.

#### Test Setup

The schematic for the transmission circuit was replicated in Advanced Design System, as shown below.


#### Figure 2.1: Transmitting block diagram

#### Data

The graphs below show the linear modulation of frequency in the generated chirps, as well as the separation of each individual chirp.


Figure 2.2: Signals produced throughout system

#### Conclusion

The subsystem correctly generated chirps, but the VCO used in the simulation has a set voltage, and is unable to change. Therefore, the proper power required at the antenna was unable to be reached. An improvement to the system above will be to incorporate a 1-4 power splitter instead of the cascading 1-2 power splitters as depicted in Figure 2.1 above. This will decrease the power loss between the generated signal and the signal passed to the antennas.

# 3 Individual Contributions Receiver Antenna

The receiving antenna will be composed of a phased array of 4 antennas to pick up the reflections transmitted. These will be amplified in proportion to the time received by the TVG, and mixed to create a complete picture of the reflections found in the range of the LNA. This signal will be converted into a digital form, which will be utilized in processing the image illustrated by the reflections that were received.

## 3.1 Significant Changes in Direction

Initial circuit system included a flow from the phased array antenna to the LNA, TVG, mixer, and ADC for image processing. However, in research of prior GPR projects, the team decided to instead have the phased array connect to the TVG then the LNA, then to the mixer and digital converter. This is due to the idea that the GPR’s objective is to detect and present a picture of all the objects in the ground hidden to the user. The LNA will increase its sensitivity to incoming noise in this implementation, up to 96 dB.

## 3.2 Subsystem Status

The subsystem currently takes in a simulated GPR receiver signal and passes it through a TVG and a LNA. The signal is simulated from a pulsed decaying sine wave of round 10 mV. The TVGs gain curve is a linear line increasing with time. The LNA has a Noise Figure of about 1.2 dB.

## 3.3 Subsystem Challenges and Solutions

While the ADS testing showed positive results for a simple 1 antenna receiver system, the team still needs to implement the phased array system. The 2 main choices are between a homodyne and heterodyne implementation. While heterodyne would yield higher quality results, the team is choosing to implement the homodyne version due to the much lower cost. The heterodyne system also utilizes a local oscillator for each receiver signal circuit path, which could add unnecessary complexity.

## 3.4 Subsystem Technical Details

The receiving antenna array consists of 4 receiver antennas that are each connected to their own subcircuit. This section expects incoming reflections that originate from the transmitter antenna. Once picked up by the phased array receiver antenna, the signal will be passed through a time varying gain amplifier. This is to compensate for loss of gain in the reflected signal. The signal then passes through a low noise amplifier system for another amplification so to notice any possible reflection. These processed signals will then pass through a mixer to sum the reflections found via autocorrelation. This final signal is converted from analog to digital and its values utilized for image processing. The antenna array consists of 4 receiver antennas that are each connected to a TVG followed by a LNA system. These are later mixed and sent to the ADC for conversion and image processing.

Below is two tables showing values obtained during testing of the time varying gain circuit and the low noise amplifier.

Table 3.2
Time Varying Gain

Parameter | Specification | Simulation Results
Gain | 1dB | 0.9 - 10.5 dB
Bandwidth | 915MHz | 915MHz

Table 3.2
Low Noise Amplifier

Parameter | Specification | Simulation Results
Gain | 2dB | 2.15dB
Bandwidth Noise Figure | 915MHz 1 - 1.5 dB | 915MHz 1.2 dB

## 3.5 Subsystem Testing

Simulating the receiving antenna circuit in Advanced Design System was the only testing we were able to perform on the subsystem so far.

### 3.5.1 ADS Simulation

The ADS simulation’s purpose was to confirm our architecture.

#### Test Setup

The schematic for the receiver circuit was replicated in Advanced Design System, as shown on the next page.


#### Figure 3.1: Receiver block diagram

The input signal was a pulsed decaying sine wave to simulate a signal that the GRP receiver might receive.


#### Figure 3.2: Receiver input diagram

#### Data

The graphs below show the signal after it passes through the TVG and LNA


Figure 3.3: Signals produced by TVG


Figure 3.4: Signals produced by LNA

#### Conclusion

The subsystem correctly applied a time varying gain to the received signal and increased the gain of the overall signal. The final design will have to be a homodyne phase array receiver, so the subsystem will need to be redesigned for this case.

# 4 Conclusions

Explain the main significance of this document. What does the information presented mean and why is it important? What is the current status of the entire project, what are the major results. New results should not be introduced in this section although recommendations for future improvements may be considered.

References

[1] Christian Wolff, “Phased Array Antenna ,” [Online]. Available at: http://www.radartutorial.eu/06.antennas/Phased%20Array%20Antenna.en.html. [Accessed: 2015]

[2] Cedric Martel, “Modelling and Design of Antennas for Ground-Penetrating Radar Systems ,” Ph.D. dissertation, Dept. Elect. Eng, Univ. of Surrey, Guildford, United Kingdom, 2002.

[3] “Ground Penetrating RADAR (GPR) (After Basson 2000) Introduction,” GPR theory, 2007. [Online]. Available at: http://www.geo-sense.com/gprmore.htm. [Accessed: Jan-2015].

[4] Standard Guide for Using the Surface Ground Penetrating Radar Method for Subsurface Investigation, Active Standard ASTM D6432, 2011

[5] A. P. Annan, "Ground Penetrating Radar Principles, Procedures & Applications," Sensors & software Inc., Mississauga, Ontario, 2003

[6] Bart Scheers, “Ultra-Wideband Ground Penetrating Radar, with Application to the Detection of Anti Personnel Landmines,” Ph.D. dissertation, Dept. Elect. Eng, Catholic Univ. of Louvain, Louvain-la-Neuve, Belgium, 2001.

[7] C. Allen , “Radar Pulse Compression ,” 2004. [Online]. Available at: https://www.ittc.ku.edu/workshops/Summer2004Lectures/Radar_Pulse_Compression.pdf. [Accessed: 2015]

[8] Cedric Martel, “Modelling and Design of Antennas for Ground-Penetrating Radar Systems ,” Ph.D. dissertation, Dept. Elect. Eng, Univ. of Surrey, Guildford, United Kingdom, 2002.

[9] “Ground Penetrating RADAR (GPR) (After Basson 2000) Introduction,” GPR theory, 2007. [Online]. Available at: http://www.geo-sense.com/gprmore.htm. [Accessed: Jan-2015].

[10] Standard Guide for Using the Surface Ground Penetrating Radar Method for Subsurface Investigation, Active Standard ASTM D6432, 2011

[11] A. P. Annan, "Ground Penetrating Radar Principles, Procedures & Applications," Sensors & software Inc., Mississauga, Ontario, 2003

[12] Bart Scheers, “Ultra-Wideband Ground Penetrating Radar, with Application to the Detection of Anti Personnel Landmines,” Ph.D. dissertation, Dept. Elect. Eng, Catholic Univ. of Louvain, Louvain-la-Neuve, Belgium, 2001.

Student Name

Team 24 Table of Contents

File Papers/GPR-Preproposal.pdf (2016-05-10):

# GPR Root Mapping System

### Pre-Proposal

12/14/15

ECEN 403 – Capstone (Senior) Design Texas A&M University, College Station, TX

Team 24
Tyler Castro
Coy Coburn
Daniel Miller
Michael Turner

Team 24
Castro, Coburn, Miller, Turner Page 2

Abstract

The goal of this project is to create a ground penetrating radar system to serve as a non-destructive method for mapping plant root systems. The system consists of two antennas, one for receiving and one for transmitting, a control unit and power supply.
A control unit will be used to pass an electrical pulse to an antenna. The antenna will transmit the signal into the ground at a frequency of 915 MHz. The signal will reflect off materials with different dielectric constants like that of roots and pipes. The strength and time required for the return of any reflected signal is measured and recorded.
Once the signal is received, the scanner will record and process the radio signals into digital signals and process an image of the recorded data for display to the user. This data is collected over a given area and a computer, using specialized software, will apply mathematical functions to the signal in order to remove background interferences. Over multiple instances, the user will have enough data from the images to observe the change in the soil composition due to the actions of the root systems absorbing and transferring water and nutrients from the soil. The software will display the strength of the reflected signal with respect to time and position in a 2-D image.
Power being delivered to the antennas must be regulated to allow the generating antenna to propagate radio waves with high enough energy to overcome the attenuation that happens as the wave travels through the ground. Output power is to be regulated according to the type of soil being penetrated, as well as the plant type to be mapped.

Team 24
Castro, Coburn, Miller, Turner Page 3
I. INTRODUCTION
A. Need Statement
Root growth is complex and little is known about the reason behind root development

patterns. Better understanding roots will offer deeper insight into water and nutrient flow in an

ecosystem, but observing root growth in an ecosystem over a period of time can be difficult, and

no good non-destructive methods are in place. A ground penetrating radar system allows for the

observation of root growth while preserving the wellbeing of the ecosystem. . Research utilizing

this project’s device can lead to improvement in farming techniques, minimizing damage to the

environment from human interaction, aid in hydrogeophysics contributions, as well as quicker

soil replenishment and reforestation.

B. Proposed System

The ground penetrating radar system can be broken down into four subsystems as shown

in Figure 1: Power, Control Unit, Antennas, and Signal processing/Display.


Fig. 1. System block diagram

Team 24
Castro, Coburn, Miller, Turner Page 4
The ground penetrating radar system depicted in Figure 2 works by using antennas to

send an electrical pulse into the ground and record the strength and the time required for the

return of any reflected signal. This technique uses high-frequency pulsed EM pulses (from 10 to

3000 MHz) sent into the ground to discover what is underneath. Reflections are produced when

radio waves pass through materials with different electrical conductivity; some of the original

signal is reflected while some continues to travel in the material until it reaches another boundary

where more of the signal is reflected or until the signal dissipates. These reflected signals are

collected using another antenna and passed into a digital processor that will create a 2-D image

using mathematical functions.

Contrary to most ground penetrating systems, we chose to use phased array antennas at a

frequency of 915MHz. A phased array antenna is exactly what it sounds like, an array of

antennas spaced half a wavelength apart. If the antenna is designed correctly, by passing the

signal through all antennas at the same time, the sinusoidal waves produced will constructively

and destructively interact with each other so that a single wave will travel in the desired direction

and cancel each other out in all other undesired directions. This will help to reduce noise in the

receiving antenna.

This frequency was selected because of the high resolution needed to detect plant roots.

Low frequencies (1-500MHz) are used in ground penetrating radar systems where a large depth

of penetration is required. Higher frequencies have lower penetration depths because more of the

signal is reflected off boundaries between different dielectric properties like that of roots. We

chose this frequency because of its depth of .7 meters, which is the optimum depth to observe

root growth.

Team 24; Page 5; Antennas; Control Unit; Power

Castro, Coburn, Miller, Turner

Signal Processor/Display

Fig. 2. Physical Sketch of the System

Material | Relative Permittivity, K | Pulse Velocities, m/Ns | Conductivity, mS/m
Sand (dry) | 4-6 | 0.15-0.12 | 0.0001 - 1
Sand (saturated) | 25 | 0.055 | 0.1 - 1

Table 1: Surface material and notable attributes

The propagation of the transmitted signal depends on electrical properties of the materials that
the signal is reflected off. The dielectric constants of these materials will influence the signal’s

echo and will be revealed in the data collected by the receiver. GPR can be done either by
continuous profiling or stationary point collection. While continuous may be quicker to cover
more area, the data received is not nearly as detailed or accurate. For the project’s scope,
stationary point collection will be the better choice given its method to stack scans multiple times
for more accurate results before moving to the next area to be scanned.

Team 24
Castro, Coburn, Miller, Turner Page 6
Relative Permittivity | 1 | 5 | 10 | 15 | 25 | 80

Frequencies

100 MHz | 3 | 1.36 | 0.96 | 0.76 | 0.6 | 0.32
200 MHz | 1.52 | 0.68 | 0.48 | 0.4 | 0.32 | 0.16
300 MHz | 1 | 0.44 | 0.32 | 0.24 | 0.2 | 0.12
500 MHz | 0.6 | 0.28 | 0.2 | 0.16 | 0.12 | 0.08
900 MHz | 0.32 | 0.16 | 0.12 | 0.08 | 0.08 | 0.04

Table 2: Radar Wavelengths for Antenna Frequencies and Relative Permittivity

Team 24
Castro, Coburn, Miller, Turner Page 7
II. CONCEPTUAL DESIGN DESCRIPTION
A. Implementation
Transmitting Antenna
| The design of the transmitting antenna is shown below in Figure 3. The coaxial oscillator

will be connected to a switch, which will be controlled by the microcontroller. The

microcontroller can be programmed to control the pulse repetition frequency and pulse duration

by completing the circuit for a period of time. A pulse from the oscillator will pass through an

attenuator and a power amplifier before being sent through the antenna array. The attenuator

helps with impedance matching with the antenna, and will lower the Voltage Standing Wave

Ratio in order to have minimal power reflection when fed to the antenna. The low noise power

amplifier will increase the power of the pulse passed through it, which will give the pulse a large

signal-to-noise ratio, allowing for clearer images to be created after signal processing. Before

reaching the antenna, the pulse will also go through a power splitter. The splitter will branch the

pulse with minimal insertion loss, so the pulse can then also be sent to the receiving end of the

antenna system for signal mixing.


Figure 3: Transmitting Antenna design

The modulator shown in figure 3 is used to implement frequency modulation for pulse

compression, as explained in the following section.

Team 24
Castro, Coburn, Miller, Turner Page 8
Pulse Compression

Pulse compression will also be implemented in our system design, which will increase

range resolution and signal to noise ratio, and allow us to balance pulse duration and consumed

power. Pulse compression can be achieved through either frequency modulation, or phase

modulation [1].

For frequency modulation, our input pulses can be modified to have a frequency that

changes linearly over the period of the pulse. This type of signal is referred to as a linear chirp.

When the received chirp is inter-correlated with our original chirp, the resulting signal has a

smaller width than the original. This improves our resolution, because received signals that are

shorter in time mean that reflections can be closer together without blending together. A visual

example of frequency modulated pulse compression is shown in figure 4. In order to change our

input pulses to chirps, a modulator can be inserted, which will produce a linear ramp function.

This ramp function will be fed into the Vtune input pin of the oscillator, which will cause the

input voltage to be proportional to the transmit frequency, creating linear chirps.


Figure 4: Linear chirp with two reflections, and the resulting echoes from matched filtering [2]

For phase modulation, the input pulse can be modified to be broken up into a series of

time slots with equal duration. These slots can be assigned a phase of either 0 or 180 degrees.

There are sequences of phases that, when correlated with itself, create a resulting pulse with

large side lobe level ratios. For example, taking the original pulse and splitting it into two, with

the first half of the pulse having a phase of 180 degrees and the second half having a phase of 0

Team 24
Castro, Coburn, Miller, Turner Page 9
degrees, relates to the Barker code of +1, -1. Correlating that pulse with itself creates a pulse

with side lobe level ratios of -6 dB. To create this example in our circuit, another switch could

be inserted to direct the first half of the pulse through a phase shifter of 180 degrees, then switch

to another line without the phase shifter for the second half of the pulse. However, this will be

difficult to achieve, as the speed of the switch would have to be impossibly fast.

Phased Antenna Array

With an antenna array, phase shift modules can be used to alter the phase of individual

antennas and direct the total radiation pattern and direction of the system. For the proposed

system, the array’s total radiation pattern can be directed to focus on a specific point to increase

the total energy of radiation. This would be helpful for when the ground has high water

concentration and attenuates RF waves greatly.

A passive phased array, where there is a single source of RF waves and a phase shift

module for each antenna in the array, would be the easiest implementation. A block diagram of

a passive phased array is shown in figure 6. Due to destructive and constructive interference, an

array of antennas has a high gain width, and low sidelobes, with the gain centered in the middle

of the array. The direction of the main lobe can be altered using the phase shifters.


Figure 6: A general representation of a passive 4 antenna phase array [3]

Team 24
Castro, Coburn, Miller, Turner Page 10
Antenna Choice
Because we only need the pulse directed in a specific area, directional antennas were

looked into for use in this project, as opposed to omnidirectional antennas. After researching

previously used antennas in similar projects, the horn antenna seemed to be the most used type of

antenna for GPR. Because horn antennas have no resonant elements, they have a wide

bandwidth, and have high antenna gain [4]. However, they are not easily constructed, and are

more expensive than antennas of more simple design. The Vivaldi antenna co-planar directional

antenna with a wide bandwidth. Vivaldi antennas are of simple design, making them low-cost.

Their combination of efficiency in both performance and price makes Vivaldi antennas the

choice for this project. A simple diagram of a Vivaldi antenna is shown in figure 7.


Figure 7: A Vivaldi Antenna

Receiving Antenna

The receiver will convert the received echo signals into a digital signal to obtain the

reflected information. The receiver with need to be sensitive, have a large fractional bandwidth,

good noise performance, and a large dynamic range. The receiver hardware will include a time

varying gain (TVG), a low noise amplifier (LNA), and sample and hold (S/H) circuit unit.

Team 24
Castro, Coburn, Miller, Turner Page 11


Figure 8: Block Diagram of Receiver Antenna []

The TVG’s purpose is to compensate for spreading losses of the transmitting signal and

reflected echo. This is done by introducing a fixed gain in dB per unit in time (or distance). In

reality, the TVG is an attenuator based in PIN diodes that can have a variable resistance as a

function of voltage. Since the first and largest reflectance is the air-ground interface, the

reflections in the ground will be seen later in time and are less attenuated. This allows for the

LNA following the TVG to be more sensitive and therefore increasing the range of the receiver.

The LNA conditions the entering RF signal to utilize the whole dynamic range. This is a

necessity due to losses mentioned earlier in the TVG section and to ensure that most, if not all,

objects in the ground are noticed and recorded in the reflected signals.

The S/H circuit unit provides a constant stable signal value for the A/D converter. The

input bandwidth must be of the same order as the highest frequency received. A full-bridge

sampler circuit has been chosen for its good linearity, noise performance, and common usage

with frequencies under 1 GHz.

With A/D converters that have conversion rates of 200 MHz for 8 bit and 10 MHz for 16

conversions, a technique is to slow down the sampling rate. Sequential sampling can do this by

converting on intersections of the slow and fast ramps, which are determined by the wanted

number of samples and PRF rate. Conversions done by the actual A/D converter with 16 bits can

have a dynamic range of 96 dB.

Team 24
Castro, Coburn, Miller, Turner Page 12
B. Analysis

Penetration depth

Penetration depth of microwave and RF power is defined as the depth where the power is

reduced to 1/e or 36.7% (e=2.718) of the power entering the surface [5]. The penetration depth of

a signal as a function of frequency is shown below (1). Using a frequency of 915 MHz and a

complex relative permittivity of sand at 20% moisture content with ε*= 20.3 - j1.17 [1], the

penetration depth was calculated to be .201 meters. Another calculation of penetration depth was

done for sand with a moisture content of 4% which resulted in a penetration depth of .733

meters. This shows that moisture content is a large factor in calculating penetration depths and

determining the moisture content of the soil before scanning is important. Note: this calculation

only shows penetration depths meaning once the signal reflects off an object the signal will then

experience an equivalent loss traveling back to the receiving antenna. For this reason, a high

power signal must be sent so that the signal can travel to these depths and return with enough

power for the antenna to receive.
dp =

c

### 2Πf√2ε′(√1+(

ε′′
ε′

)

2−1)

(1)

. 201 ≅

3E8
2Π(915E6)√2(20.3)(√1+(
1.17
20.3

)

2−1)

(20% MC) (1)

. 733 ≅

3E8
2Π(915E6)√2(3.33)(√1+(
.13
3.33

)

2−1)

(4% MC) (1)

Team 24
Castro, Coburn, Miller, Turner Page 13

### References

[1] C. Allen , “Radar Pulse Compression ,” 2004. [Online]. Available at: https://www.ittc.ku.edu/workshops/Summer2004Lectures/Radar_Pulse_Compression.pdf. [Accessed: 2015]
[2] Flambe , "Chirp before" and “Chirp compr” 2006. [Online]. Available at: https://commons.wikimedia.org/wiki/File:Chirp_before.jpg#/media/File:Chirp_before.jpg and https://commons.wikimedia.org/wiki/File:Chirp_compr.jpg#/media/File:Chirp_compr.jpg. [Accessed: 2015]
[3] “Phased Array” 2003. [Online.] Available at: http://encyclopedia2.thefreedictionary.com/Phased+array+radar. [Accessed: 2015].
[4] “The Horn Antenna” 2009. [Online.] Available at: http://www.antenna-theory.com/antennas/aperture/horn.php. [Accessed: 2015].
[5] V. Komarov, S. Wang, and J. Tang , “Permittivity and Measurements ,” 2005. [Online]. Available at: http://public.wsu.edu/~sjwang/dp-rf-mw.pdf. [Accessed: 2015].
[6] Cedric Martel, “Modelling and Design of Antennas for Ground-Penetrating Radar Systems ,” Ph.D. dissertation, Dept. Elect. Eng, Univ. of Surrey, Guildford, United Kingdom, 2002.
[7] “Ground Penetrating RADAR (GPR) (After Basson 2000) Introduction,” GPR theory, 2007. [Online]. Available at: http://www.geo-sense.com/gprmore.htm. [Accessed: Jan-2015].
[8] Standard Guide for Using the Surface Ground Penetrating Radar Method for Subsurface Investigation, Active Standard ASTM D6432, 2011
[9] A. P. Annan, "Ground Penetrating Radar Principles, Procedures & Applications," Sensors & software Inc., Mississauga, Ontario, 2003
[10] Bart Scheers, “Ultra-Wideband Ground Penetrating Radar, with Application to the Detection of Anti Personnel Landmines,” Ph.D. dissertation, Dept. Elect. Eng, Catholic Univ. of Louvain, Louvain-la-Neuve, Belgium, 2001.

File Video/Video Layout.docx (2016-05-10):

:0 - :28, intro

- Generic maroon, team name, professors, sponsor

:28 - :56, how gprs works

- Block diagram, highlights topics as it goes on

:56 - 1:58, daniel subsystem

1:58 - 3:02 tyler subsystem

- Block diagram
- Both parts
- Antenna
- RF choke

3:02 - 3:38 michael subsystem

- Block diagram
- Block diagram and LNA
- Block diagram and Shottky

3:38 - 4:41 Coy subsystem

4:41 - 5:19 Conclusion

5:19 - 5:25 Final Statement

- Generic maroon thank you

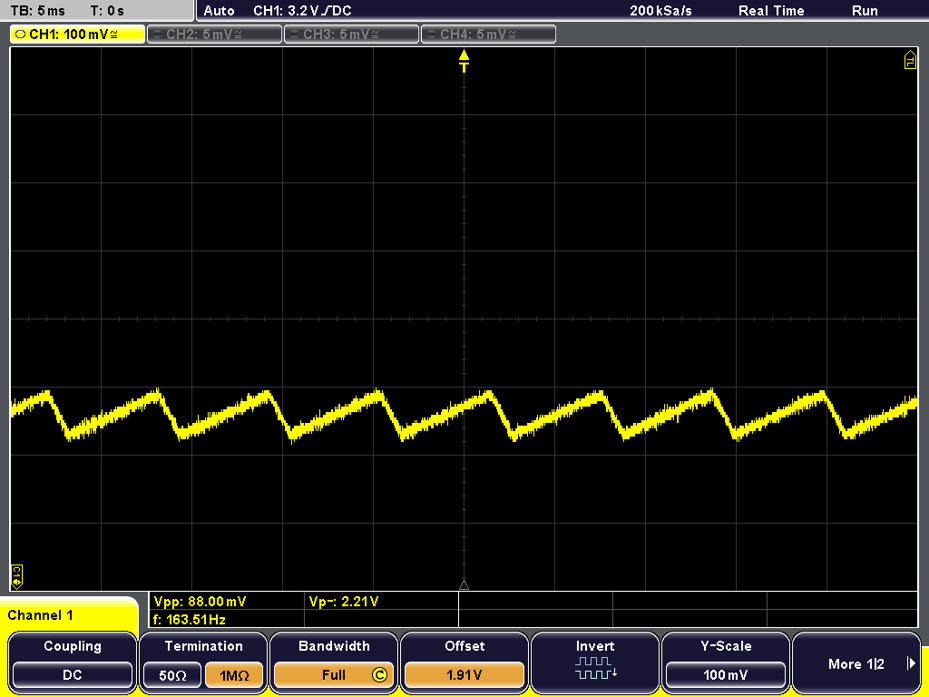
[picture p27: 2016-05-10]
photos/TransmitSignal.png

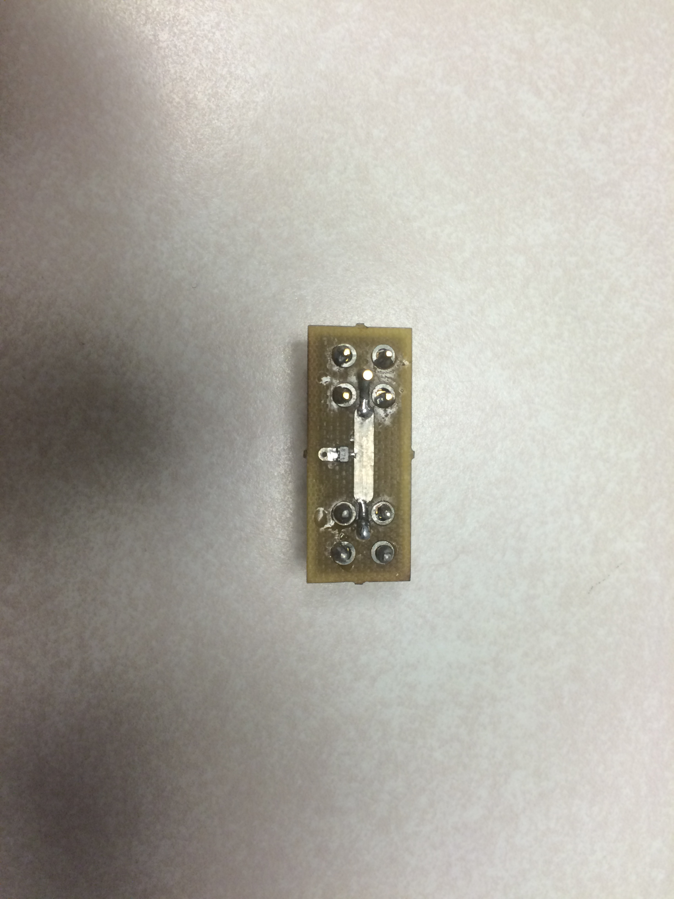
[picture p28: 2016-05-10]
photos/Schottky Diode Clamp.JPG

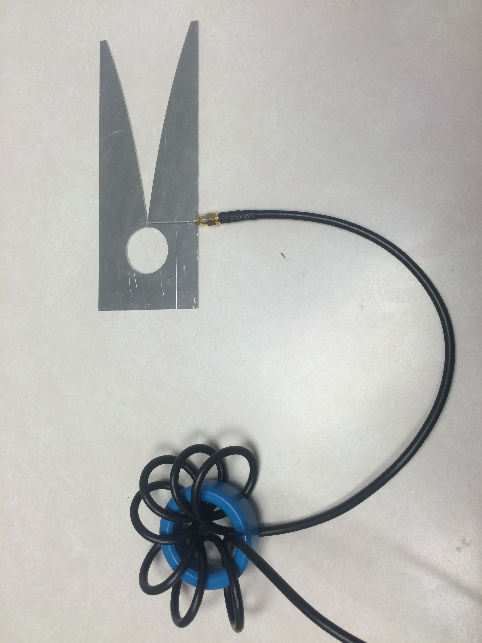
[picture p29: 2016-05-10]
photos/Atenna Subsystem.JPG

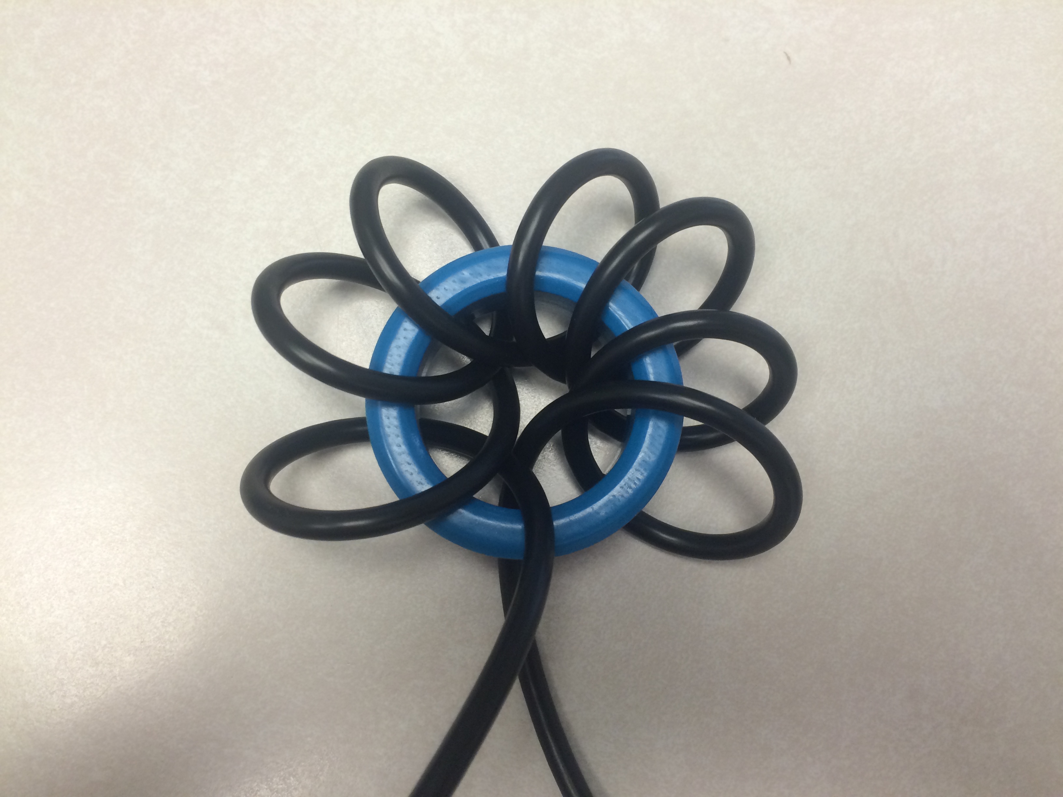
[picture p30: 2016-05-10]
photos/RF Choke.JPG

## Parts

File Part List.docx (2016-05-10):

TEAM 24 - GROUND PENETRATING RADAR

Part List

- Large Box
  - Bag 1
    - 10 - 6” SMA MM Cables (https://cinchconnectivity.com/OA_MEDIA/specs/pi-415-0025-006.pdf)
    - 8 - 24” SMA MM Cables (https://cinchconnectivity.com/OA_MEDIA/specs/pi-415-0025-006.pdf)
    - 1 - Schottky PCB
    - 1 - LNA Eval board (TB-757+ (http://www.minicircuits.com/pcb/WTB-757+_P02.pdf))
    - 1 - Power Splitter Eval board (TB-37 (http://www.minicircuits.com/pcb/WTB-37_P02.pdf))
    - 2 - Power Amplifier
    - 2 - Unknown 8 pin (used in signal generator)
    - 2 - 2” SMA-F / Open Cable
  - Bag 2
    - 18 - Power Spliter (BP2U+ (https://www.minicircuits.com/pdfs/BP2U+.pdf))
    - 20 - LNA (CMA-5043+ (https://www.minicircuits.com/pdfs/CMA-5043+.pdf))
    - 8 - SMA surface mount connectors (CONSMA001-SMD-G (https://www.linxtechnologies.com/resources/diagrams/consma001-smd-g.pdf))
    - 1 - 8’ RG58 SMA-M / N-Type M Cable
    - 1 - Toroidal Core
  - Box 1
    - 20 - LNA (TAV-541+ (http://www.minicircuits.com/pdfs/TAV-541+.pdf))
    - 4 - LNA Eval board (TB-154 (http://www.minicircuits.com/pcb/WTB-154_P02.pdf))
  - Box 2
    - 19 - schottky diodes (1PS70SB84 (http://www.nxp.com/documents/data_sheet/1PS70SB82_84_85_86.pdf))
    - 1 - ADC
    - 1 - ADC driver
    - 1 - ADC driver board
    - 1 - LPF/AAF Filter PCB
    - 1 - Function Generator / Power amplifier PCB
    - 1 - VCO
    - 1 - Mixer
  - 1 - Handcrafted Steel Antenna
  - 2 - Machine Fab Aluminum Antenna
  - 2 - 5’ RG58 SMA - F / SMA - M Cable
  - 2 - Toroidal Core

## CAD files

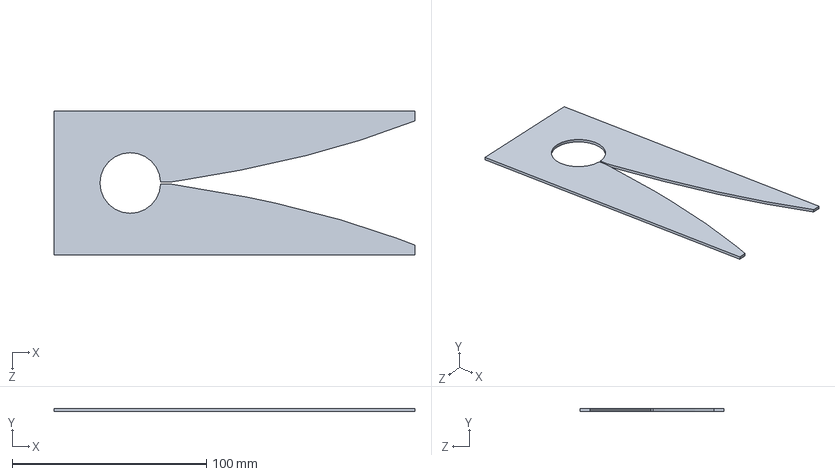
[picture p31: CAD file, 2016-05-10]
Design Files/Antenna/Vivaldi Antenna.SLDPRT
186.0 x 1.59 x 74.0 mm

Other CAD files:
Design Files/Antenna/Vivaldi Antenna.SLDDRW

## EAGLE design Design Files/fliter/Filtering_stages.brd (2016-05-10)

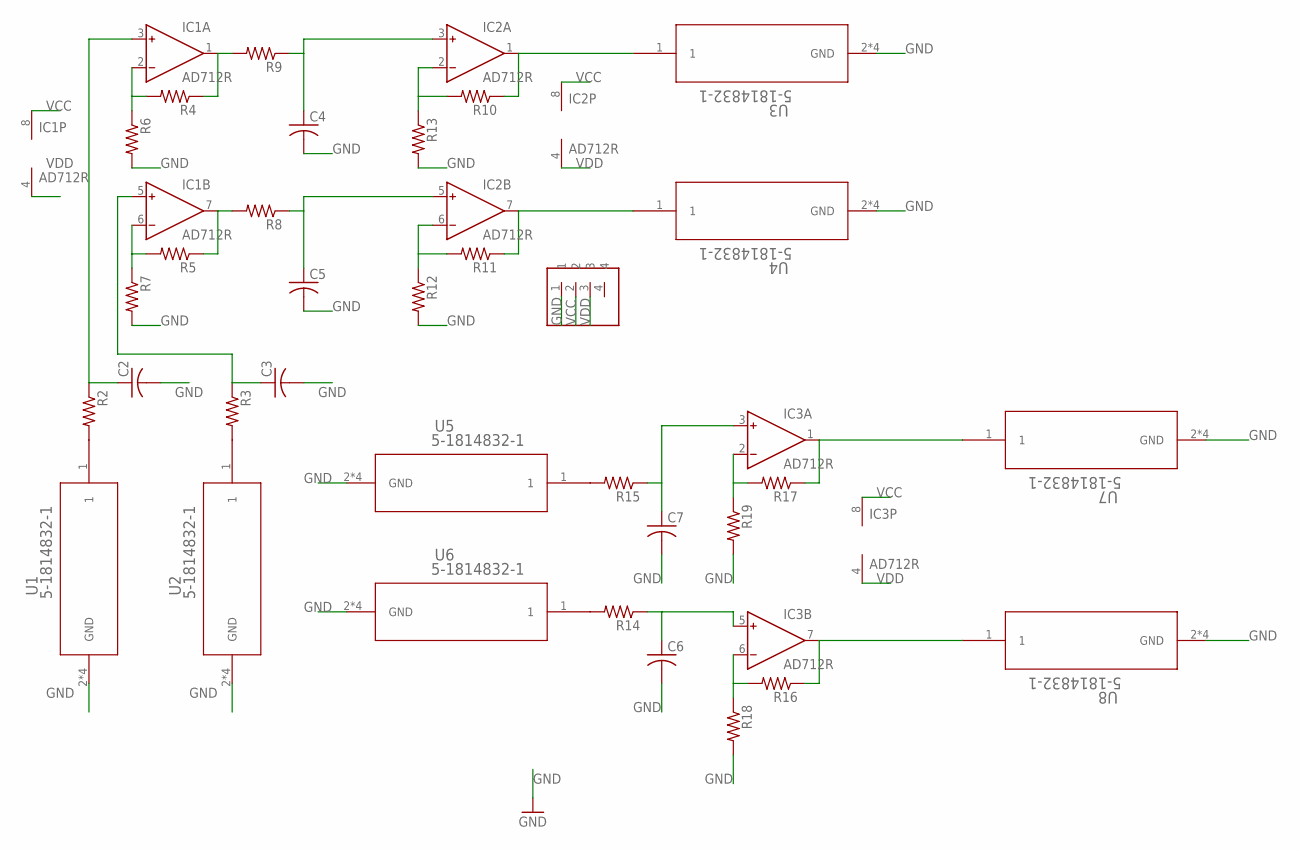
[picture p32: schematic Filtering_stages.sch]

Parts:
C2, C3, C4, C5, C6, C7: C-US025-025X050; C025-025X050
IC1, IC2, IC3: AD712R; SO8
R2, R3, R4, R5, R6, R7, R8, R9, R10, R11, R12, R13, R14, R15, R16, R17, R18, R19: R-US_0204/7; 0204/7
U1, U2, U3, U4, U5, U6, U7, U8: 5-1814832-1
U$1: ED2582-ND

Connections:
GND: C2.2, C3.2, C4.2, C5.2, C6.2, C7.2, R6.2, R7.2, R12.2, R13.2, R18.2, R19.2, U1.2 (GND), U1.3 (GND), U1.4 (GND), U1.5 (GND), U2.2 (GND), U2.3 (GND), U2.4 (GND), U2.5 (GND), U3.2 (GND), U3.3 (GND), U3.4 (GND), U3.5 (GND), U4.2 (GND), U4.3 (GND), U4.4 (GND), U4.5 (GND), U5.2 (GND), U5.3 (GND), U5.4 (GND), U5.5 (GND), U6.2 (GND), U6.3 (GND), U6.4 (GND), U6.5 (GND), U7.2 (GND), U7.3 (GND), U7.4 (GND), U7.5 (GND), U8.2 (GND), U8.3 (GND), U8.4 (GND), U8.5 (GND), U$1.1
unnamed: R2.2, U1.1
unnamed: R3.2, U2.1
unnamed: C2.1, IC1.3 (IN+), R2.1
unnamed: C3.1, IC1.5 (IN+), R3.1
unnamed: IC1.6 (IN-), R5.2, R7.1
unnamed: IC1.7 (OUT), R5.1, R8.2
unnamed: IC1.1 (OUT), R4.1, R9.2
unnamed: IC1.2 (IN-), R4.2, R6.1
unnamed: C4.1, IC2.3 (IN+), R9.1
unnamed: IC2.2 (IN-), R10.2, R13.1
unnamed: IC2.6 (IN-), R11.2, R12.1
unnamed: IC2.1 (OUT), R10.1, U3.1
unnamed: IC2.7 (OUT), R11.1, U4.1
unnamed: C5.1, IC2.5 (IN+), R8.1
unnamed: R14.2, U6.1
unnamed: R15.2, U5.1
unnamed: C7.1, IC3.3 (IN+), R15.1
unnamed: IC3.2 (IN-), R17.2, R19.1
unnamed: IC3.1 (OUT), R17.1, U7.1
unnamed: C6.1, IC3.5 (IN+), R14.1
unnamed: IC3.6 (IN-), R16.2, R18.1
unnamed: IC3.7 (OUT), R16.1, U8.1
VCC: IC1.8 (V+), IC2.8 (V+), IC3.8 (V+), U$1.2
VDD: IC1.4 (V-), IC2.4 (V-), IC3.4 (V-), U$1.3

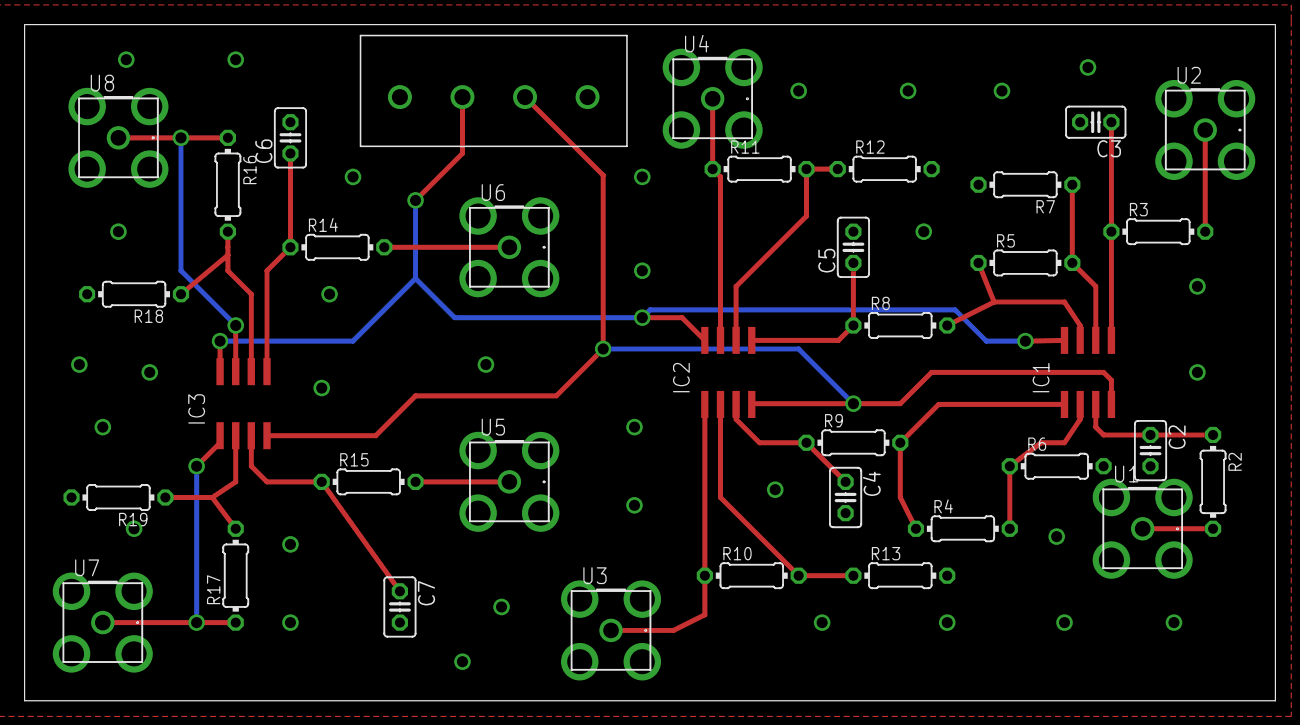
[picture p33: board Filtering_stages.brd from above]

Board: 2 copper layers, 101.6 x 54.9 mm, 36 parts (0 on the bottom side), 25 nets.

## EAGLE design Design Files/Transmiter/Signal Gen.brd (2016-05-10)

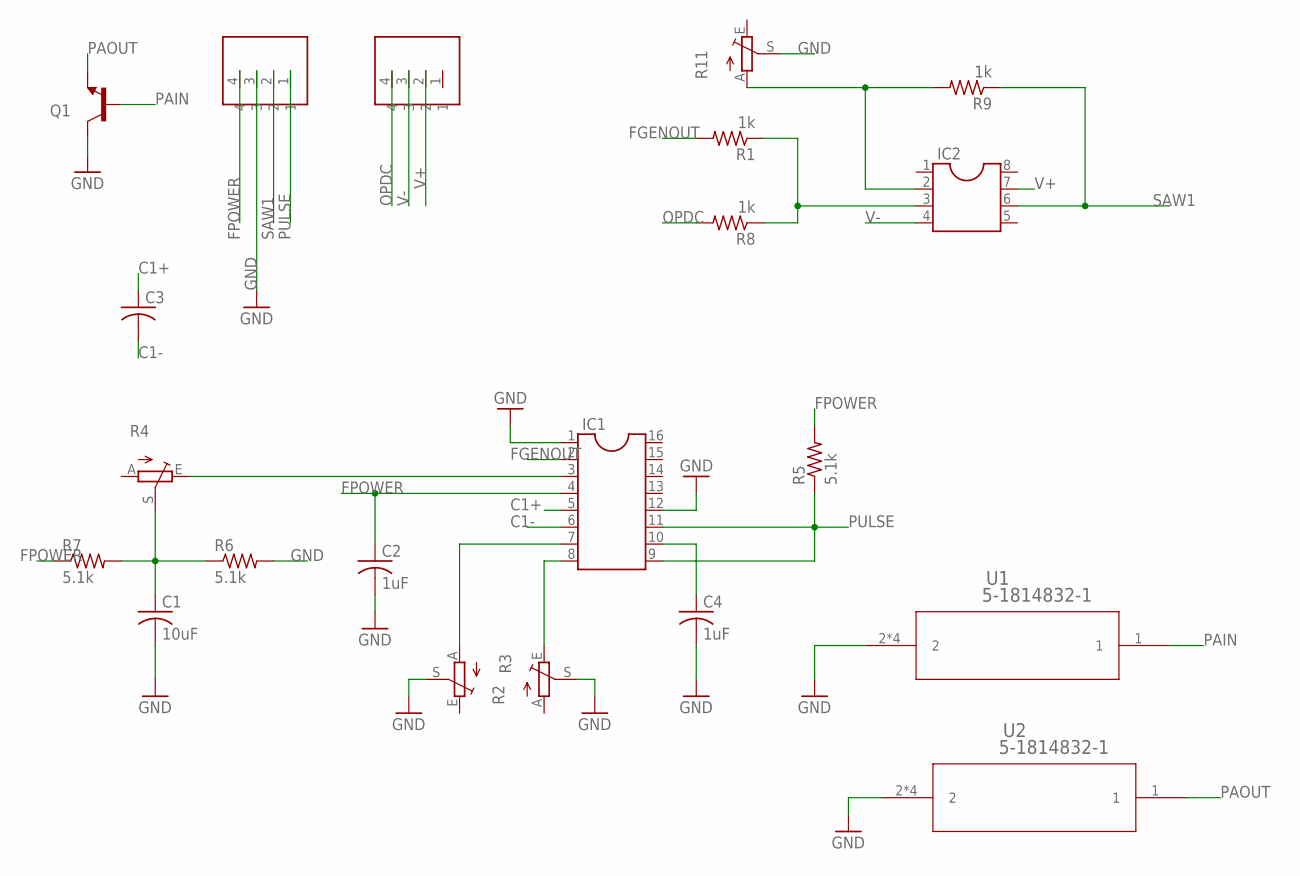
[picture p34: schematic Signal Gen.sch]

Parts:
C1: 10uF; C025-025X050
C2, C4: 1uF; C025-025X050
C3: C-US025-025X050; C025-025X050
IC1: DIL16S; SOCKET-16
IC2: DIL8S; SOCKET-08
Q1: TRANSISTOR_NPNSOT89; SOT89
R1, R8, R9: 1k; 0204/7
R2, R3: TRIM_EU-B25U; B25U
R4: TRIM_EU-B64W; B64W
R5, R6, R7: 5.1k; 0204/7
R11: TRIM_EU-RJ9W; RJ9W
U1, U2: 5-1814832-1
U$1, U$2: ED2582-ND

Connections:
C1+: C3.1, IC1.5
C1-: C3.2, IC1.6
FGENOUT: IC1.2, R1.2
FPOWER: C2.1, IC1.4, R5.2, R7.1, U$1.4
GND: C1.2, C2.2, C4.2, IC1.1, IC1.12, Q1.2 (C), R2.S, R3.S, R6.2, R11.S, U1.2, U1.3 (2), U1.4 (2), U1.5 (2), U2.2, U2.3 (2), U2.4 (2), U2.5 (2), U$1.3
unnamed: IC1.3, R4.E
unnamed: C1.1, R4.S, R6.1, R7.2
unnamed: IC1.7, R3.A
unnamed: IC1.8, R2.E
unnamed: C4.1, IC1.10
unnamed: IC2.3, R1.1, R8.1
unnamed: IC2.2, R9.2, R11.A
OPDC: R8.2, U$2.4
PAIN: Q1.1 (B), U1.1
PAOUT: Q1.3 (E), U2.1
PULSE: IC1.9, IC1.11, R5.1, U$1.1
SAW1: IC2.6, R9.1, U$1.2
V+: IC2.7, U$2.2
V-: IC2.4, U$2.3

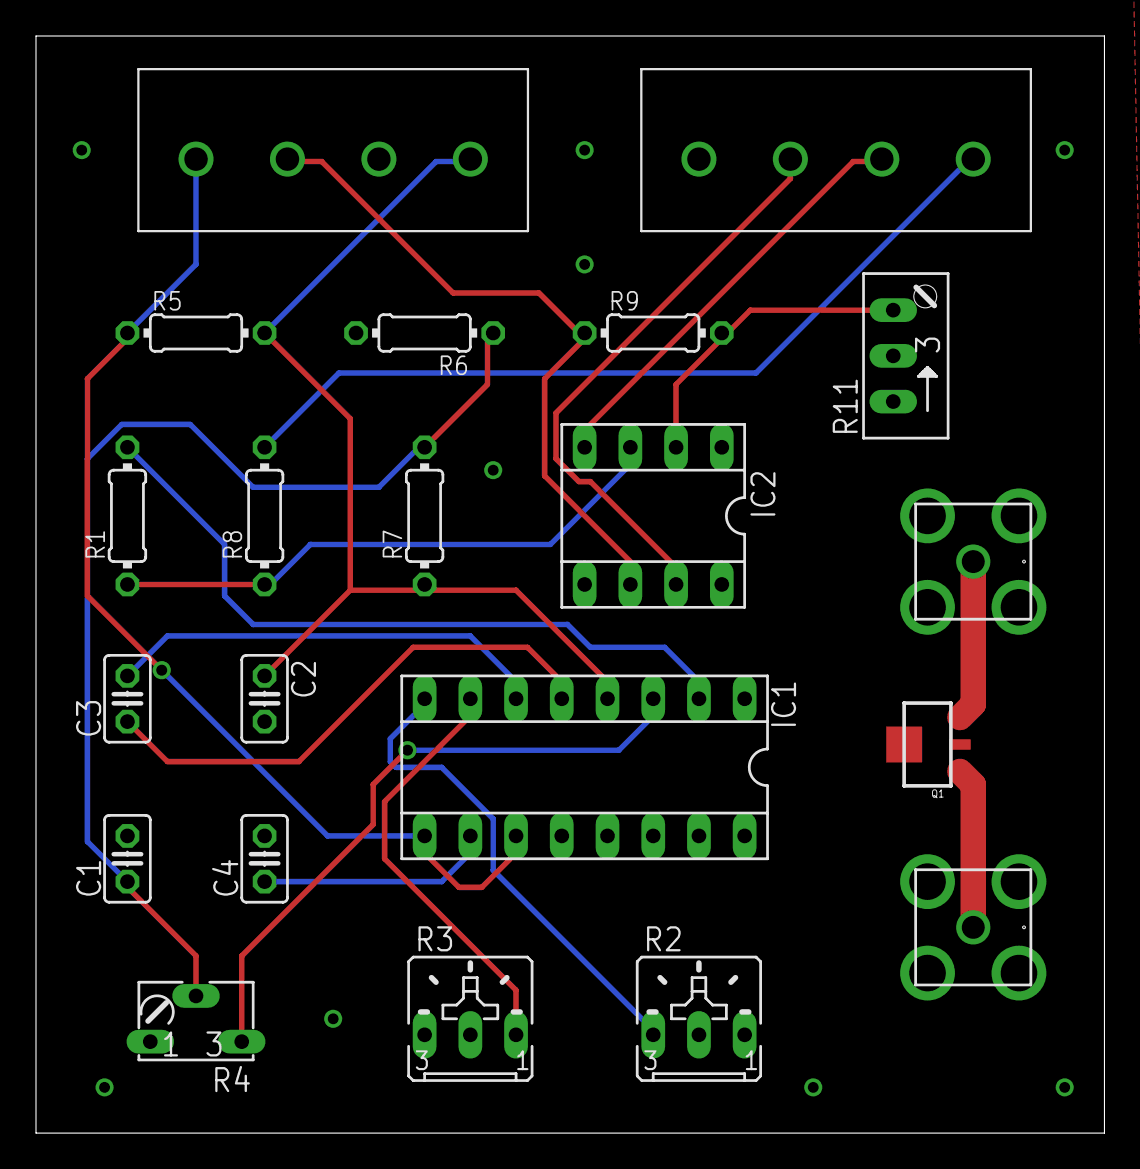
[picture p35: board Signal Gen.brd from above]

Board: 2 copper layers, 59.4 x 61.0 mm, 21 parts (0 on the bottom side), 19 nets.

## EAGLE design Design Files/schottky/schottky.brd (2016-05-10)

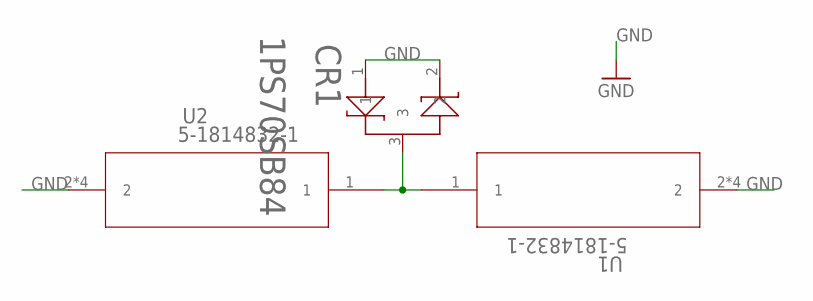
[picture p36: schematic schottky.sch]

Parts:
CR1: 1PS70SB84; SOT323
U1, U2: 5-1814832-1

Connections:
GND: CR1.1, CR1.2, U1.2, U1.3 (2), U1.4 (2), U1.5 (2), U2.2, U2.3 (2), U2.4 (2), U2.5 (2)
unnamed: CR1.3, U1.1, U2.1

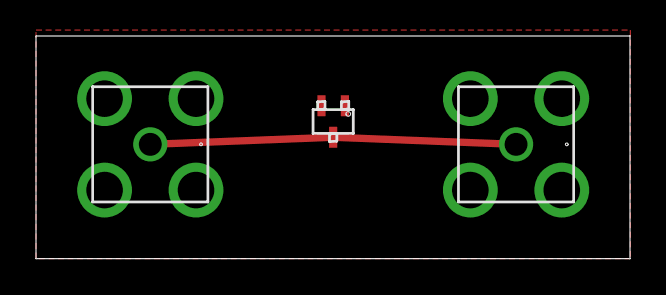
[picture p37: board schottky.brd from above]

Board: 2 copper layers, 33.0 x 12.4 mm, 3 parts (0 on the bottom side), 2 nets.

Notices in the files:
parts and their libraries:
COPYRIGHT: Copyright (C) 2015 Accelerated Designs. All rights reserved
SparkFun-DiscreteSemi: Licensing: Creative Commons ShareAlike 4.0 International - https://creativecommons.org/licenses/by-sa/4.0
